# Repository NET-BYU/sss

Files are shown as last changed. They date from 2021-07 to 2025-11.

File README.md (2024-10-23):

# Seven Segment Sign

    

## Welcome to the Seven Segment Sign! (SSS)
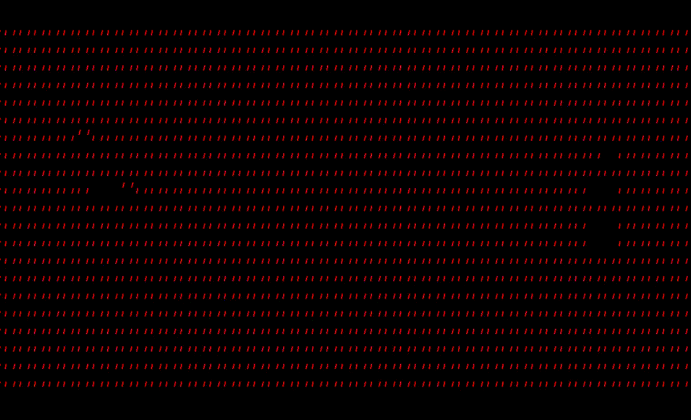
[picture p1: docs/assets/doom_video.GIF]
ricky


## Getting Started
Here are some helpful links to get you up and running!
- [API Docs](https://sss.readthedocs.io/en/latest/API/Display/)
- [Install on Linux/Mac](https://sss.readthedocs.io/en/latest/Installation/Install%20SSS%20on%20Mac%20or%20Linux/)
- [Install on Windows](https://sss.readthedocs.io/en/latest/Installation/Install%20SSS%20on%20Windows/)
- [Create your first demo](https://sss.readthedocs.io/en/latest/Tutorials/Creating%20a%20demo/)

## Common Commands
Although thorough information on how to [get started](https://sss.readthedocs.io/en/latest/Overview/Get%20started/) is in the docs, here are some quick commands you can run in order to get rolling **once you have everything installed**:

- Run the PyGame Simulator for the SSS
  ```bash
  python3 main.py simulator
  ```
- Run a specific demo in the simulator
  ```bash
  python3 main.py demo <demo_name> -s
  ```
- Start the SSS in kiosk mode
  ```bash
  python3 main.py kiosk
  ```
- To view log output of varying degrees, use the `-v` option (the more `v`'s the more `v`erbose the output becomes

For any other help or a list of comprehensive commands, run
```bash
python3 main.py --help
```

## Reporting an Issue
We love feedback! As the SSS codespace expands and acquires new features, we realize that some bugs will fall through the cracks. Please feel free to open a new issue if you notice any bugs in the code, mistakes or missing information in the documentation, or if you want a new feature to be added to the project.

You can go to the **Issues** tab to create a new issue. Please be mindful to choose the correct template for the right type of question. Apart from the currently open issues from before this writing, any **issue that does not conform to the template may become stale or be closed without warning.**

## Submitting a PR
If you are feeling creative and you would like to contribute a demo but you are outside of our organization, you are more than welcome to submit a pull request and we will look it over! 

In order for a pull request to be merged, we have the following three policies:
1. Your code must have adequate, meaningful comments. Don't feel like you have to explain every statement, but also don't write comments like `# This a loop that goes over all the values`.
2. Your PR will need approval from **at least 2 org members**. Users who respond to these the most are @apal6981, @christopolise, and @philipbl
3. Your code **MUST** be formatted with `black`. This is as simple as adding the [Black Formatter](https://marketplace.visualstudio.com/items?itemName=ms-python.black-formatter) to VS/OSS Code or running `python3 -m black <your py files>`

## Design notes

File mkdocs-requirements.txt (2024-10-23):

mkdocs
mkdocs-autorefs
mkdocs-bootstrap386
mkdocs-bootswatch
mkdocs-git-revision-date-localized-plugin
mkdocs-material
mkdocs-material-extensions
mkdocs-rtd-dropdown
mkdocs-windmill-dark
mkdocstrings[python]
griffe

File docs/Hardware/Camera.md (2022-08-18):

The purpose of a camera module exists thanks mainly thanks to the creative camera demo by [Bryson Schiel](https://www.linkedin.com/in/bryson-s-82926aa6/). While any camera which streams to an IP address will work with the demo, we have provided an inexpensive option which integrates nicely with the SSS. This module is centered around the ESP-CAM kit and it's firmware. All of these files are available in the [hw/camera](https://github.com/NET-BYU/sss/tree/docs/hw/camera) directory of the project. All of these files were designed and provided by [Carter Pollan](https://github.com/virginia2244).

## Camera PCB Blueprints

### Backpack Schematic
The ESP-CAM normally comes with its own backpack which provides power. An optional set of pins was included in the design to allow for a peripheral to connect to the camera if necessary. The backpack that we have provides power and also a breakout to connect devices to some of the GPIO pins.

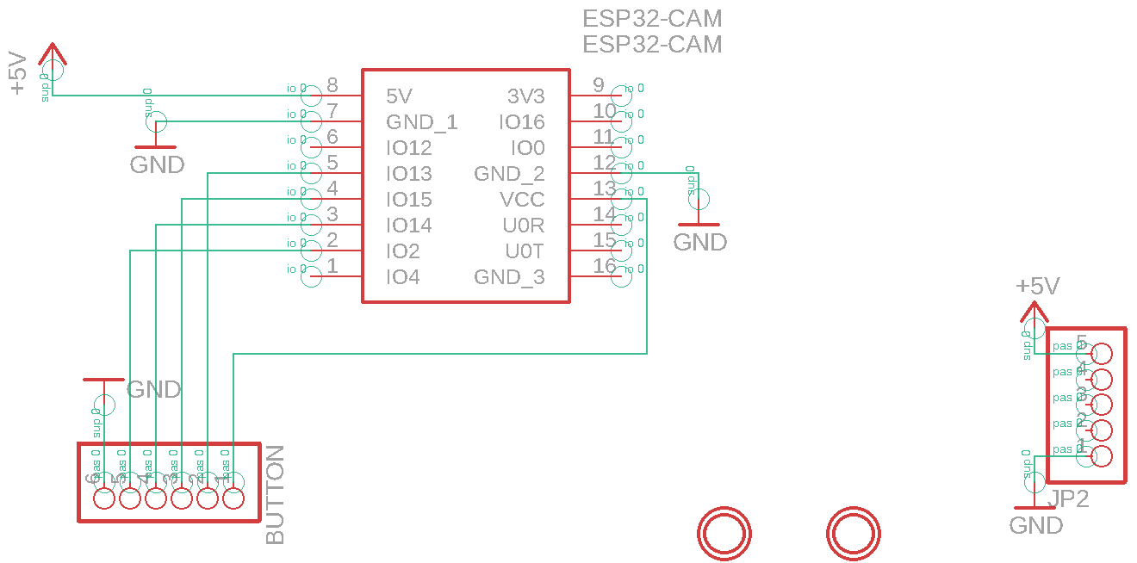
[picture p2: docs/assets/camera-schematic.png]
backpack-sch


### Backpack PCB
This PCB is single-sided and has no vias which means that it can be etched on the most simple of mills. It also features some groovy, curved traces for a nice aesthetic. [Check this video out](https://youtu.be/euJgtLcWWyo) to see why melty boards are superior.

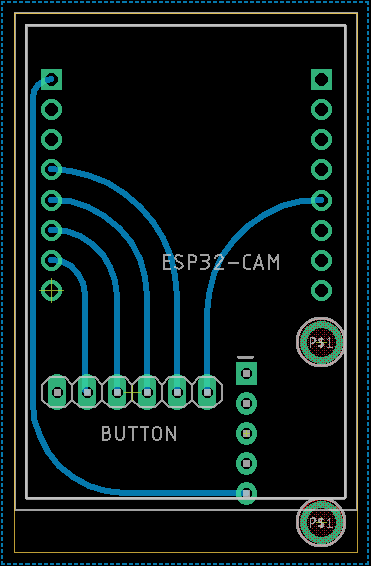
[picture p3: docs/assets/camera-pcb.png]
backpack-pcb


## Camera Enclosure

For those who aren't a big fan of have a jumbled mess of wires and PCBs, a sleek two piece case has also been designed to encapsulate and mount the camera module.  

### Lid

<!-- Import maps polyfill -->
<!-- Remove this when import maps will be widely supported -->
<script async src="https://unpkg.com/es-module-shims@1.3.6/dist/es-module-shims.js"></script>

<script type="importmap">
    {
        "imports": {
            "three": "../../assets/three.module.js"
        }
    }
</script>

<script type="module">

    import * as THREE from 'three';

    import { OrbitControls } from '../../assets/OrbitControls.js';
    import { ThreeMFLoader } from '../../assets/3MFLoader.js';

    let camera, scene, renderer, object, loader, controls;

    var container = document.getElementById('camera-lid');

    init();

    function init() {

        renderer = new THREE.WebGLRenderer( { antialias: true, alpha: true } );
        renderer.setPixelRatio( window.devicePixelRatio );
        renderer.setSize( 500, 300 );
        renderer.setClearColor( 0x000000, 0 ); // the default
        container.appendChild( renderer.domElement );
        renderer.domElement.style.cursor = "grab";

        scene = new THREE.Scene();

        scene.add( new THREE.AmbientLight( 0xffffff, 0.2 ) );

        camera = new THREE.PerspectiveCamera( 15, window.innerWidth / window.innerHeight, 1, 500 );

        // Z is up for objects intended to be 3D printed.

        camera.up.set( 0, 0, 1 );
        camera.position.set( - 100, - 250, 100 );
        scene.add( camera );

        controls = new OrbitControls( camera, renderer.domElement );
        controls.addEventListener( 'change', render );
        controls.minDistance = 50;
        controls.maxDistance = 400;
        controls.enablePan = false;
        controls.update();

        const pointLight = new THREE.PointLight( 0xffffff, 0.8 );
        camera.add( pointLight );

        const manager = new THREE.LoadingManager();

        manager.onLoad = function () {

            const aabb = new THREE.Box3().setFromObject( object );
            const center = aabb.getCenter( new THREE.Vector3() );

            object.position.x += ( object.position.x - center.x );
            object.position.y += ( object.position.y - center.y );
            object.position.z += ( object.position.z - center.z );

            controls.reset();

            scene.add( object );
            render();

        };

        loader = new ThreeMFLoader( manager );
        loadAsset( '../../assets/cam-lid-sss.3mf' );

        // window.addEventListener( 'resize', onWindowResize );

    }

    function loadAsset( asset ) {

        loader.load( asset, function ( group ) {

            if ( object ) {

                object.traverse( function ( child ) {

                    if ( child.material ) child.material.dispose();
                    if ( child.material && child.material.map ) child.material.map.dispose();
                    if ( child.geometry ) child.geometry.dispose();

                } );

                scene.remove( object );

            }

            object = group;

        } );

    }

    function onWindowResize() {

        camera.aspect = window.innerWidth / window.innerHeight;
        camera.updateProjectionMatrix();

        renderer.setSize( window.innerWidth, window.innerHeight );

        render();

    }

    function render() {

        renderer.render( scene, camera );

    }

</script>

<script type="module">

    import * as THREE from 'three';

    import { OrbitControls } from '../../assets/OrbitControls.js';
    import { ThreeMFLoader } from '../../assets/3MFLoader.js';

    let camera, scene, renderer, object, loader, controls;

    var container = document.getElementById('camera-body');

    init();

    function init() {

        renderer = new THREE.WebGLRenderer( { antialias: true, alpha: true } );
        renderer.setPixelRatio( window.devicePixelRatio );
        renderer.setSize( 500, 300 );
        renderer.setClearColor( 0x000000, 0 ); // the default
        container.appendChild( renderer.domElement );
        renderer.domElement.style.cursor = "grab";

        scene = new THREE.Scene();

        scene.add( new THREE.AmbientLight( 0xffffff, 0.2 ) );

        camera = new THREE.PerspectiveCamera( 15, window.innerWidth / window.innerHeight, 1, 500 );

        // Z is up for objects intended to be 3D printed.

        camera.up.set( 0, 0, 1 );
        camera.position.set( - 100, - 250, 100 );
        scene.add( camera );

        controls = new OrbitControls( camera, renderer.domElement );
        controls.addEventListener( 'change', render );
        controls.minDistance = 50;
        controls.maxDistance = 400;
        controls.enablePan = false;
        controls.update();

        const pointLight = new THREE.PointLight( 0xffffff, 0.8 );
        camera.add( pointLight );

        const manager = new THREE.LoadingManager();

        manager.onLoad = function () {

            const aabb = new THREE.Box3().setFromObject( object );
            const center = aabb.getCenter( new THREE.Vector3() );

            object.position.x += ( object.position.x - center.x );
            object.position.y += ( object.position.y - center.y );
            object.position.z += ( object.position.z - center.z );

            controls.reset();

            scene.add( object );
            render();

        };

        loader = new ThreeMFLoader( manager );
        loadAsset( '../../assets/cam-case-sss.3mf' );

        // window.addEventListener( 'resize', onWindowResize );

    }

    function loadAsset( asset ) {

        loader.load( asset, function ( group ) {

            if ( object ) {

                object.traverse( function ( child ) {

                    if ( child.material ) child.material.dispose();
                    if ( child.material && child.material.map ) child.material.map.dispose();
                    if ( child.geometry ) child.geometry.dispose();

                } );

                scene.remove( object );

            }

            object = group;

        } );

    }

    function onWindowResize() {

        camera.aspect = window.innerWidth / window.innerHeight;
        camera.updateProjectionMatrix();

        renderer.setSize( window.innerWidth, window.innerHeight );

        render();

    }

    function render() {

        renderer.render( scene, camera );

    }

</script>

<span>

### Case

</span>

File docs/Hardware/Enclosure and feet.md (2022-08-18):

## Enclosure

The enclosure for the physical SSS is made out of two an acryllic (**NOT POLYCARBONATE**) plexiglass fastened together by 18 x M3 screws in a 20mm standoff. The SVG files in [hw/enclosure](https://github.com/NET-BYU/sss/tree/docs/hw/enclosure) can be loaded onto a plasma/laser cutter to create the pieces.

### Front Piece
The shape and the mounting holes are seen in this figure below:

enclosure-front-sss

### Back Piece
The shape and the mounting holes are also seen on this piece. The upper group of 4 holes in the center allows for the mounting of a Raspberry Pi. The lower five are mounting holes for the [power and breakout board](Power%20Board.md). The slender slots allow for [resistors soldered to the `clk` and `din` pins](Panel.md) to poke out while the larger openings allow for the commnication and power cable to plug into the SSS's panels.

enclosure-back-sss

## Feet

The feet for the SSS are 3D printed pieces that allow for each panel (both front and back) to insert and stand inside it. The more feet are put on the bottom of the enclosure, the more stable it will be.

<script async src="https://unpkg.com/es-module-shims@1.3.6/dist/es-module-shims.js"></script>

<script type="importmap">
    {
        "imports": {
            "three": "../../assets/three.module.js"
        }
    }
</script>

<script type="module">

    import * as THREE from 'three';

    import { OrbitControls } from '../../assets/OrbitControls.js';
    import { ThreeMFLoader } from '../../assets/3MFLoader.js';

    let camera, scene, renderer, object, loader, controls;

    var container = document.getElementById('camera-lid');

    init();

    function init() {

        renderer = new THREE.WebGLRenderer( { antialias: true, alpha: true } );
        renderer.setPixelRatio( window.devicePixelRatio );
        renderer.setSize( 500, 300 );
        renderer.setClearColor( 0x000000, 0 ); // the default
        container.appendChild( renderer.domElement );
        renderer.domElement.style.cursor = "grab";

        scene = new THREE.Scene();

        scene.add( new THREE.AmbientLight( 0xffffff, 0.2 ) );

        camera = new THREE.PerspectiveCamera( 15, window.innerWidth / window.innerHeight, 1, 500 );

        // Z is up for objects intended to be 3D printed.

        camera.up.set( 0, 0, 1 );
        camera.position.set( - 100, - 250, 100 );
        scene.add( camera );

        controls = new OrbitControls( camera, renderer.domElement );
        controls.addEventListener( 'change', render );
        controls.minDistance = 50;
        controls.maxDistance = 400;
        controls.enablePan = false;
        controls.update();

        const pointLight = new THREE.PointLight( 0xffffff, 0.8 );
        camera.add( pointLight );

        const manager = new THREE.LoadingManager();

        manager.onLoad = function () {

            const aabb = new THREE.Box3().setFromObject( object );
            const center = aabb.getCenter( new THREE.Vector3() );

            object.position.x += ( object.position.x - center.x );
            object.position.y += ( object.position.y - center.y );
            object.position.z += ( object.position.z - center.z );

            controls.reset();

            scene.add( object );
            render();

        };

        loader = new ThreeMFLoader( manager );
        loadAsset( '../../assets/feet-sss.3mf' );

        // window.addEventListener( 'resize', onWindowResize );

    }

    function loadAsset( asset ) {

        loader.load( asset, function ( group ) {

            if ( object ) {

                object.traverse( function ( child ) {

                    if ( child.material ) child.material.dispose();
                    if ( child.material && child.material.map ) child.material.map.dispose();
                    if ( child.geometry ) child.geometry.dispose();

                } );

                scene.remove( object );

            }

            object = group;

        } );

    }

    function onWindowResize() {

        camera.aspect = window.innerWidth / window.innerHeight;
        camera.updateProjectionMatrix();

        renderer.setSize( window.innerWidth, window.innerHeight );

        render();

    }

    function render() {

        renderer.render( scene, camera );

    }

</script>

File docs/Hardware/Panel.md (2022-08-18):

The panels of the SSS are the crux of its hardware. If you are going to attempt to replicate the SSS, it is recommended that you look at the the [Known Problems](#known-problems) and address some of those issues. However, for history and current hardware maintenance sake, we will include the current design of the panels.

## Panel PCB Blueprints

### Panel Schematics

Each panel has a group of 12 [MAX7219](https://www.maximintegrated.com/en/products/power/display-power-control/MAX7219.html) led drivers which control 8 seven segment digits. All of the ICs receive the CS, SCLK, VCC, and GND from a common trace. The MOSI coming from the Raspberry Pi enters into the first IC and is passed through all of them by tying the DOUT (output) of the preceding IC to the DIN (input). The start of the bus for the panel (SV1) receives the following from the [power board](Power%20Board.md):

1. GND
2. LOAD (CS)
3. CLK (SCLK)
4. DIN (MOSI)
5. VCC

Originally, the panels were going to be connected together by connecting the busses by having a corresponding 5 pins out (SV2) to connect to the next panel's 5 pins in (SV1). This design made the traces very long and was susceptible to noise and caused a lot of screen artifacts. Instead, each panel receives info from the [power board](Power%20Board.md) via a cable which plugs into the beginning connector of the bus.

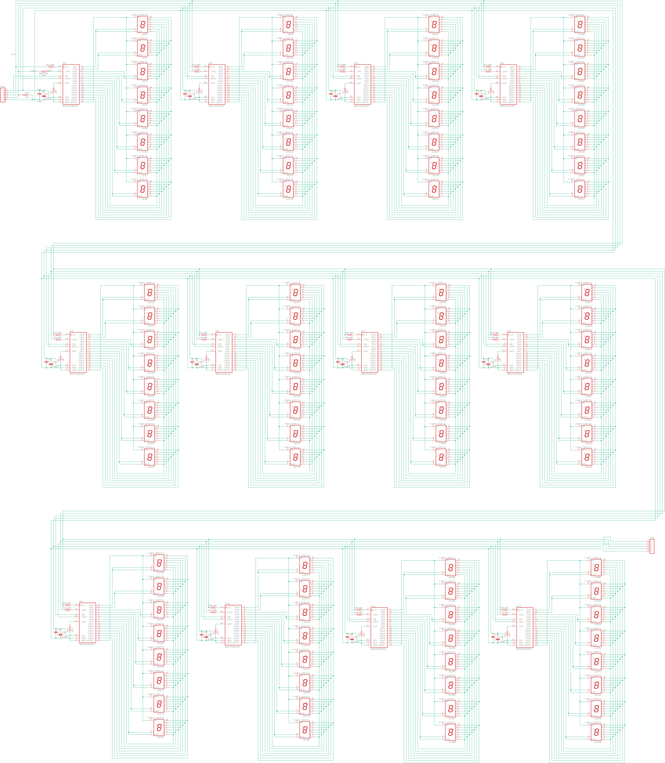
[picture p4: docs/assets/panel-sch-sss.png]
panel-sch-sss


_**Not shown in schematic:** each SCLK and DIN pin on the IC has a resistor of 200Ω+ between it and the trace. This is a hack and should be dealt with in a future hardware design version._

### Panel PCB

The PCB design is a double-sided board. The backside is where the 12 ICs, 12 resistors, 24 capacitors, and 2 cable headers are mounted. The frontside is where the 96 seven segment LED digits are mounted.

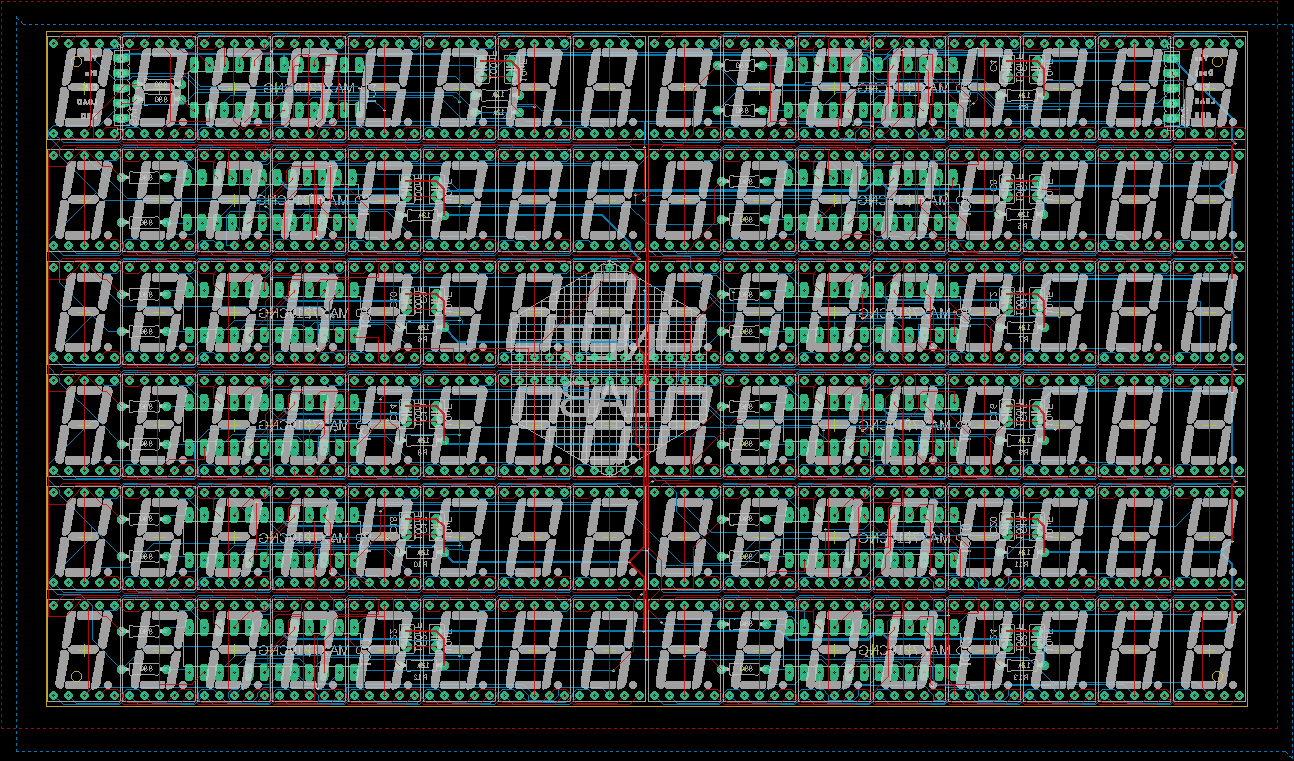
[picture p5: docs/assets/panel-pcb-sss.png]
panel-pcb-sss


### Panel

This is the back view of manufactured panel. Note that the SV1 input from the [power board](Power%20Board.md) is on the right hand side of the board and that the set of output pin pads need not be used.

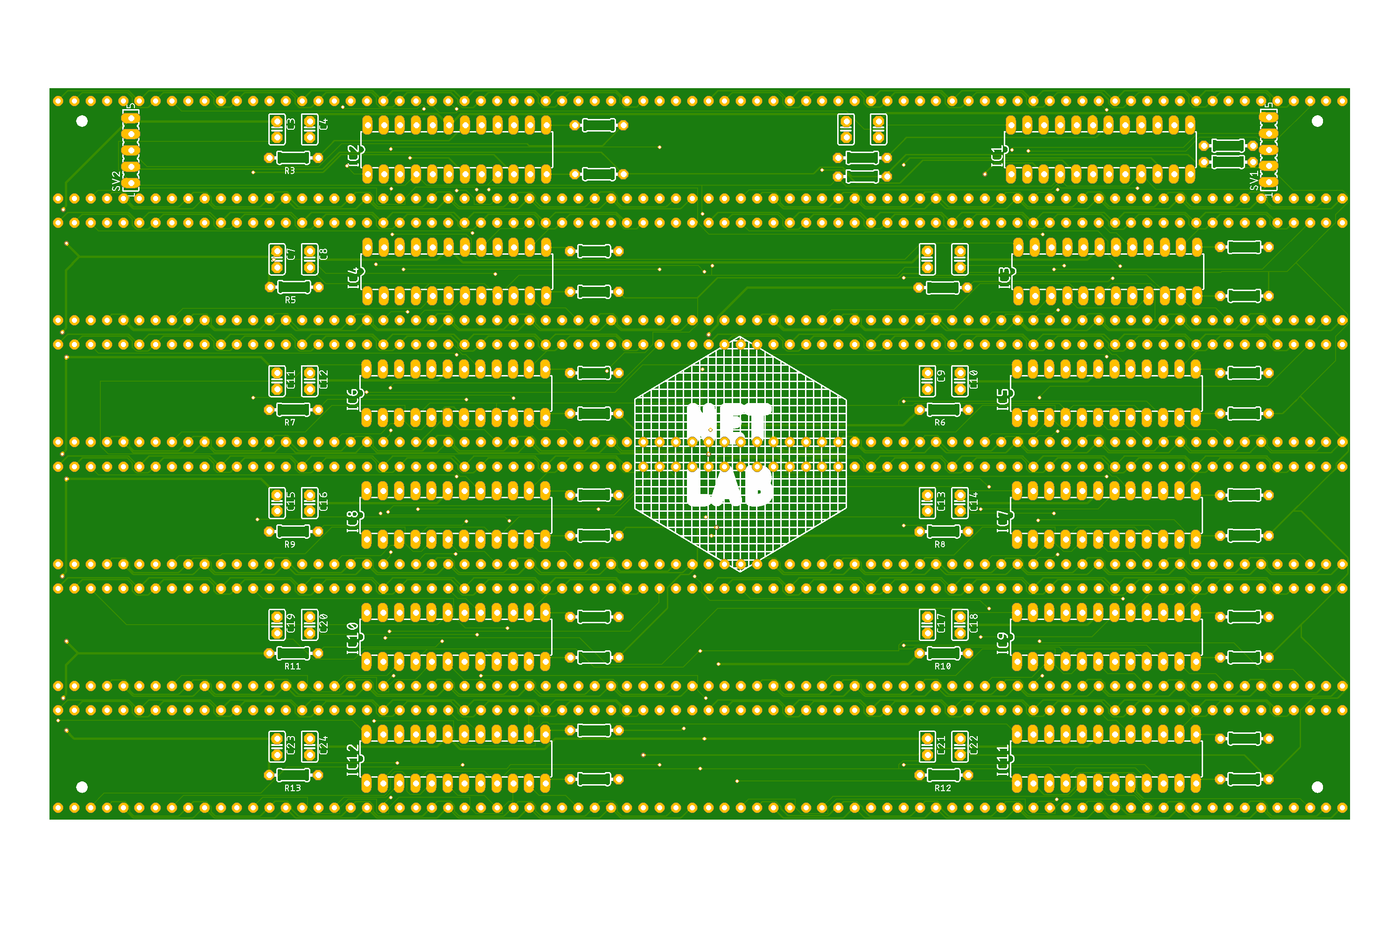
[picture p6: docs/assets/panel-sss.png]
panel-sss


## Known Problems

The current version of the SSS panel is flawed. Among the known problems are:

 - The output pins are not needed
 - The data and clock traces are very long, thin, and susceptible to noise. Changing the trace widths and paths would be necessary.
 - Using some sort of differential grounding might also reduce overall board noise.

 Any efforts to redesign the panels are more than welcome!

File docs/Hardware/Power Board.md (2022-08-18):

## Power Board PCB Blueprints

The power board is a breakout board which takes the SPI protocol wires from the [Raspberry Pi IO](Raspberry%20Pi%20IO.md) and passes them on to the each of the individual [panels](Panel.md). Along with the SPI protocol wires, this board will also power the SSS panels.

### Power Board Schematics

The power board receives all of the Raspberry Pi IO on its 8 x 2 Raspberry Pi headers and reroutes them to the BOARD_n headers. These BOARD_n pins will connect to the SV1 pins on the panels. There is also a barrel jack on this board where a DC adapter that outputs 5V and 4A will supply power to all of the ICs and LED seven segment digits on the panels of the SSS.

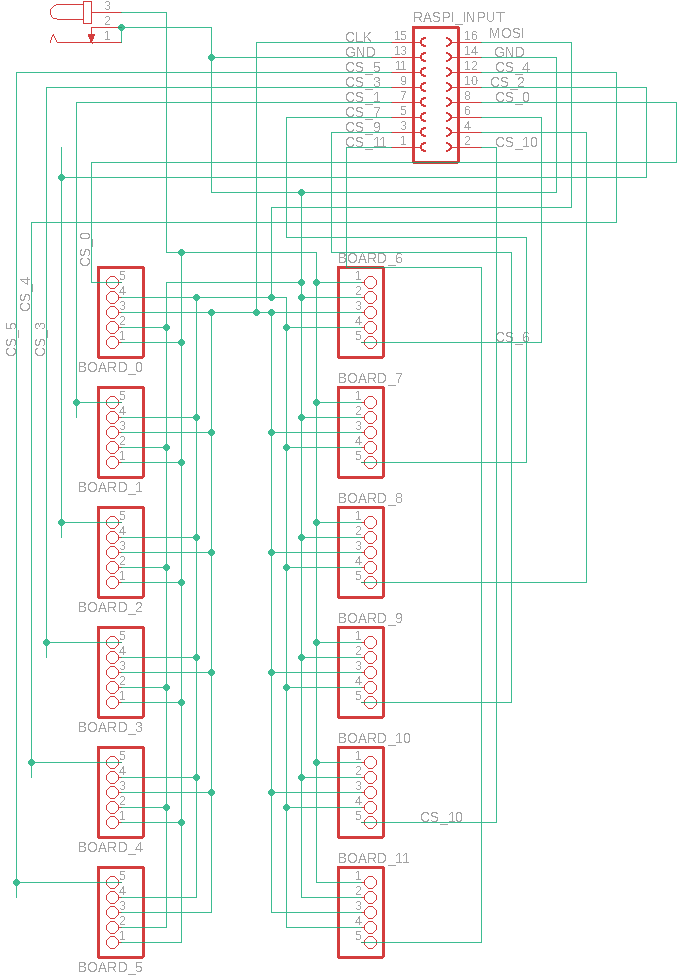
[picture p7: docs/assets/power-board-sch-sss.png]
power-board-sch-sss


### Power Board PCB
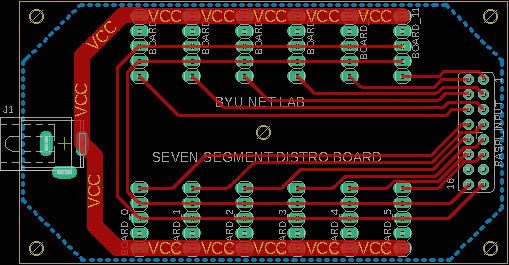
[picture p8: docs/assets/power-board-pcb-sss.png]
power-board-pcb-sss


### Power Board
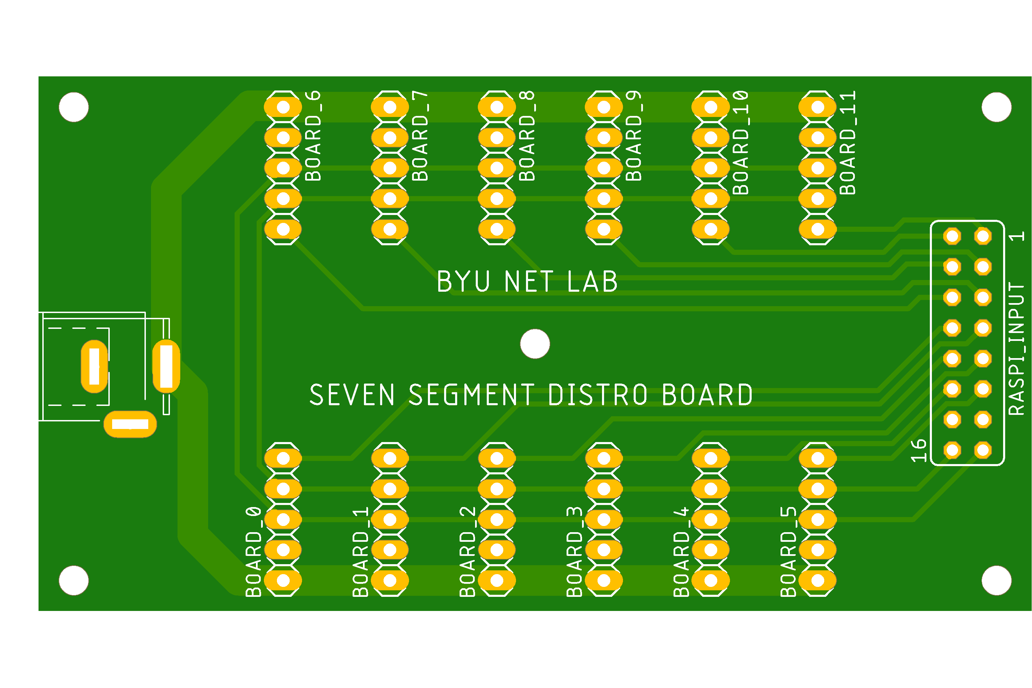
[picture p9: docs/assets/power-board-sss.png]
power-board-sss


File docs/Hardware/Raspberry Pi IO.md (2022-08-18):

At the center of the SSS is the Raspberry Pi, a compact, inexpensive computer that has a very accessible hardware interface. The SSS takes advantage of this interface and connects to all of its [panels](Panel.md) through the Pi's GPIO. Checkout this [link](https://pinout.xyz) to get an interactive guide to the GPIO.

## SPI Interface
The communication protocol the SSS uses to draw to all of the panels is the Serial Peripheral Interface (or SPI for short). We won't go into the [exact details](https://www.circuitbasics.com/basics-of-the-spi-communication-protocol/) of how this protocol works, but suffice it to say there are several connections necessary to make this work:

- **MOSI (Master Out Slave In)**: The actual binary instruction which tell the panel what to draw to the screen.
- **CS (Chip Select)**: This wire has to be on (or high) in order to receive and apply instructions from MOSI. There is one of these for each panel in our project.
- **SCLK (Clock Signal)**: This wire has an oscillating high-low timing signal that helps all the CS wires and MOSI stay in sync with each other.

## Device Tree Overlay
As you start exploring the Raspberry Pi GPIO its SPI busses (or groups of pins meant to act as a SPI device) you'll notice they only have 1 or 2 CS pins max. This means that by default, a Raspberry Pi can talk to two separate devices (or in our case, panels) at a time. This becomes a problem considering that the SSS has 12 panels!

We can overcome this problem by reassigning some of the GPIO pins on the Pi to be CS pins for our SPI bus. To do this, we will need to create a device tree overlay, or a special configuration file which reminds the Raspberry Pi's operating system on startup to make these changes to the pin definitions.

### Creating the Device Tree Source file

For those who are interested to see how this works, please refer to the [official documentation](https://www.raspberrypi.com/documentation/computers/configuration.html#device-trees-overlays-and-parameters) from Raspberry Pi on how to create a valid device tree source (`dts`) file and compile it. [sss.dts](https://raw.githubusercontent.com/NET-BYU/sss/docs/dts/sss.dts) has been provided for those who wish to copy the same configuration as the original SSS or to use it as reference.

A brief summary of what is accomplished in the file, the reassigning of certain GPIO pins, is depicted in the table below and can be used as reference in creating altered `dts` files:

#### GPIO to CS for SPI Bus 0 Reassignment
<table>
  <tr>
    <th>GPIO Pin</th>
    <td>6</td>
    <td>13</td>
    <td>19</td>
    <td>26</td>
    <td>25</td>
    <td>1</td>
    <td>12</td>
    <td>16</td>
    <td>20</td>
    <td>21</td>
    <td>17</td>
    <td>27</td>
    <td>22</td>
  </tr>
  <tr>
    <th>CS No.</th>
    <td>2</td>
    <td>3</td>
    <td>4</td>
    <td>5</td>
    <td>6</td>
    <td>7</td>
    <td>8</td>
    <td>9</td>
    <td>10</td>
    <td>11</td>
    <td>12</td>
    <td>13</td>
    <td>14</td>
  </tr>
</table>

### Compiling the `dts` into a `dtbo`
After a correctly formatted `dts` is made, it needs to be compiled into a device tree blob overlay (`dtbo`). This is a binary file is referred to upon boot and makes the appropriate changes in pin definition.

To compile the `dts` file:
```bash
dtc -@ -I dts -O dtb -o sss.dtbo sss.dts
```

After the `dtbo` binary is created, it needs to be moved or copied into the directory where GPIO overlays for the Pis are held:

```bash
sudo cp sss.dtbo /boot/overlays
```

Finally we will edit the boot config file to let the Pi know that we want to apply the overlay we just created:

```bash
sudo nano /boot/config.txt
```

Add this line to the file, notice how the first field of the assigned value to `dtoverlay` is our desired `dtbo` file name and the rest of the `cs<num>_pin` correspond to the table in the previous section.

```
dtoverlay=sss,cs2_pin=6,cs3_pin=13,cs4_pin=19,cs5_pin=26,cs6_pin=25,cs7_pin=1,cs8_pin=12,cs9_pin=16,cs10_pin=20,cs11_pin=21,cs12_pin=17,cs13_pin=27,cs14_pin=22
```

Now reboot your device and the changes should take effect!

## Pi Wiring

In our build of the SSS we connected the GPIO of the Raspberry Pi to a breakout board which distributes the CS signal to its respective panel and the MOSI, SCLK, GND, and VCC signals to the rest.



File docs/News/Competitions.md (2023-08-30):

## BYU IT&CSA 2022 Raspberry Pi Competition

The SSS was presented at the BYU IT&CSA 2022 Raspberry Pi competition with efforts to convince judges of its practical, educational, and IoT capabilities. Ashton Palacios and Chris Kitras represented the original team of contributors at the event and took first prize.

<figure class="image mx-auto" style="max-width: 750px">
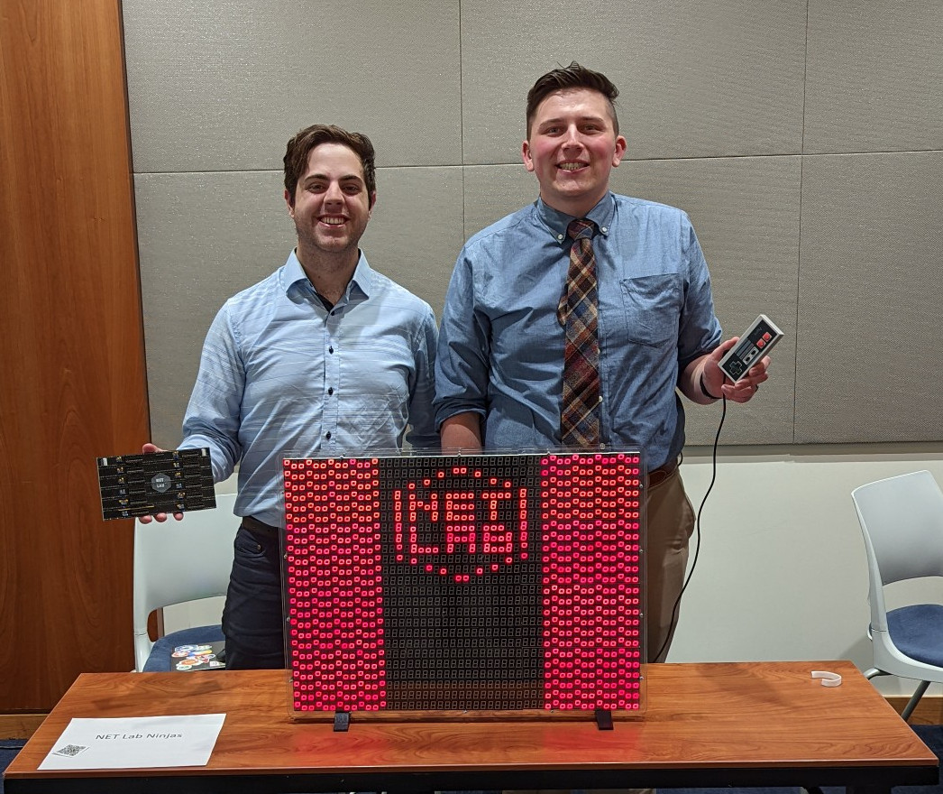
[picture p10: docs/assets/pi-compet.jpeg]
Units of the course.
  
  <figcaption style="text-align: center;">Chris Kitras (left) holding a single panel of the SSS and Ashton Palacios (right) holding an NES controller which is one possible input for the SSS.</figcaption>
</figure>

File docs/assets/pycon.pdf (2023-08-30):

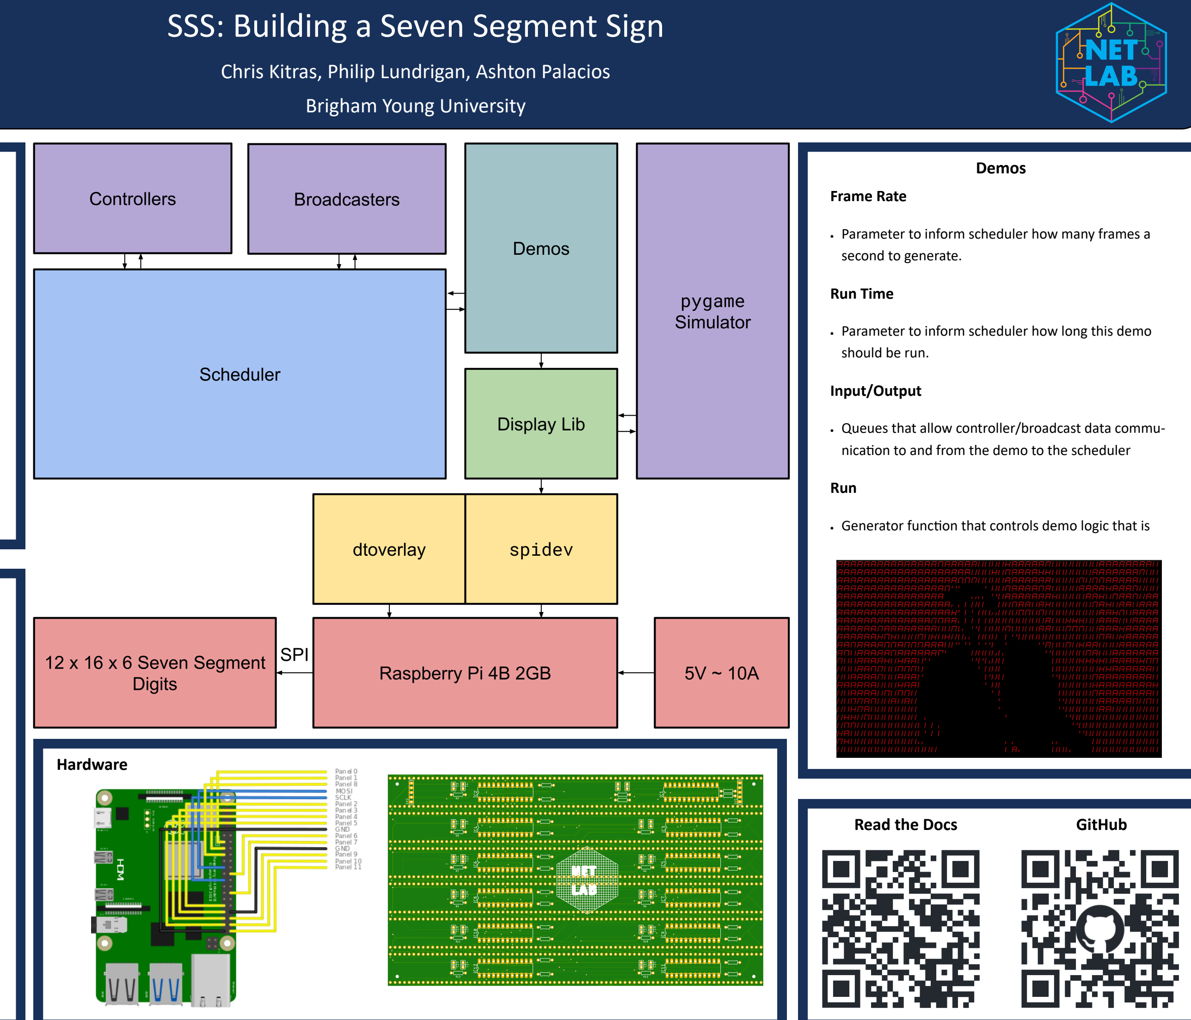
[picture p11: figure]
SSS: Building a Seven Segment Sign; Brigham Young University; Read the Docs; GitHub; Demos; Frame Rate; second to generate.; Run Time; should be run.; Input/Output; Run; Hardware

## Chris Kitras, Philip Lundrigan, Ashton Palacios

Architecture

Scheduler:

- Generators are the core underpinnings of our system. The scheduler calls each subsystem’s run/tick function which quickly performs a single action and yields control back to the scheduler.

Controllers:

- Demos can have input ranging from a physical game controller to a web based app.

Broadcasters:

- Demo and system outputs can be broadcast over the internet to different services.

Display Library:

- Custom Python library that abstracts away drawing to a physical screen or simulated pygame screen.

Introduction

Using a Raspberry Pi, 1152 seven-segment displays, and Python, we built a Seven Segment Sign (SSS). The project is designed to make something familiar and boring (seven-segment displays) into something remarkable. We designed a modular circuit board that combines hundreds of displays into one cohesive display. We created a Python library to abstract all of the hardware details of the sign to make it easy for new Python developers to write applications for the SSS. We have created multiple games and demos to show what the SSS can do. And, of course, we even ported Doom. We make extensive use of Python generators to design our system. We made our system modular so that it can receive input from multiple sources, like a game controller or the network using a smartphone.

- Parameter to inform scheduler how many frames a
- Parameter to inform scheduler how long this demo
- Queues that allow controller/broadcast data communication to and from the demo to the scheduler
- Generator function that controls demo logic that is

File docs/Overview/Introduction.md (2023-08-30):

# Introduction

The Seven Segment Sign, or SSS for short, is a purely Python, Raspberry Pi-powered system that drives a screen of 1152 seven segment digits (arranged in a 48 x 24 array). But don't let these low specs fool you! This platform provides a beginner-friendly opportunity for anyone to learn how to address complex design problems with strict limitations. Some of the initial demos we've been able to make work are:

### Video Player

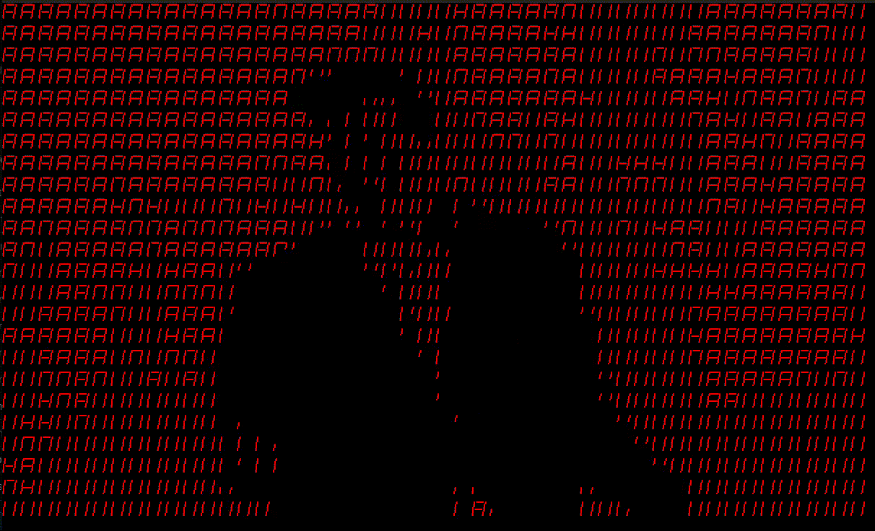
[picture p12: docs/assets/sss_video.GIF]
video


### Arcade Games

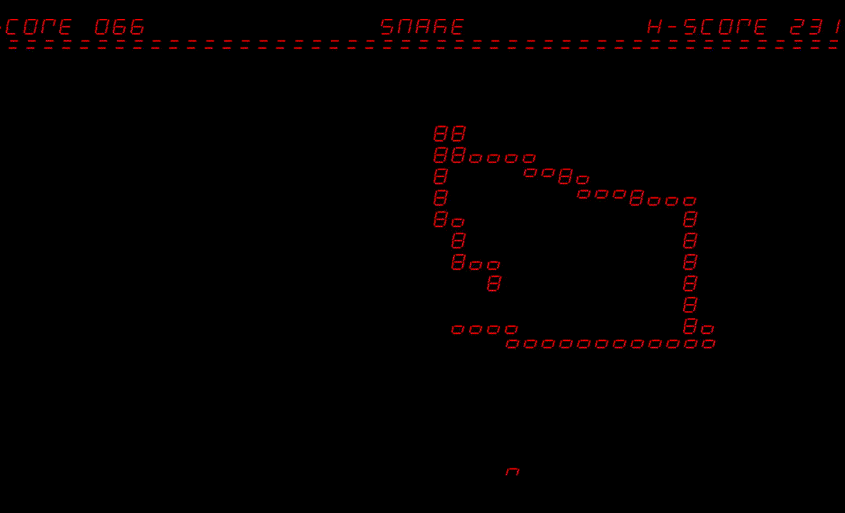
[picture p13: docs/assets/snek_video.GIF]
snek


### and even Doom!

doom

## What next?
 Even though the physical SSS resides in the [BYU NET Lab](https://netlab.byu.edu), the source code, blueprints, and a simulator are all available on [GitHub](https://www.github.com/NET-BYU/sss) and this wiki! 
 
 Take a look at the following links to help you get started:

 - [Get started](Get%20started.md)
 - [Support](../Troubleshooting/Support.md)

Happy hacking!

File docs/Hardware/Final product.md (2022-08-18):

## Front of SSS

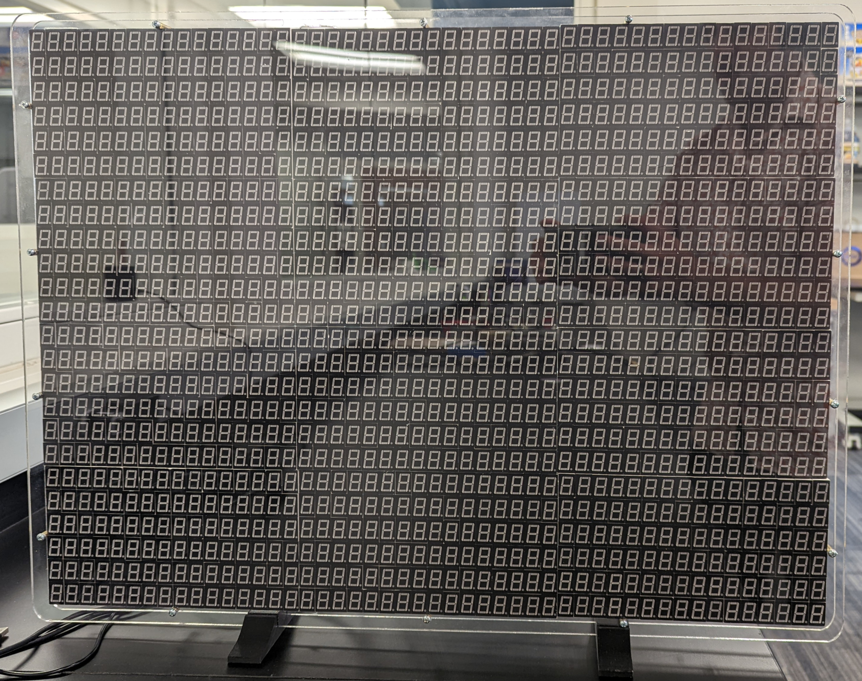
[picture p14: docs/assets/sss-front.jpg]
sss-front


## Back of SSS

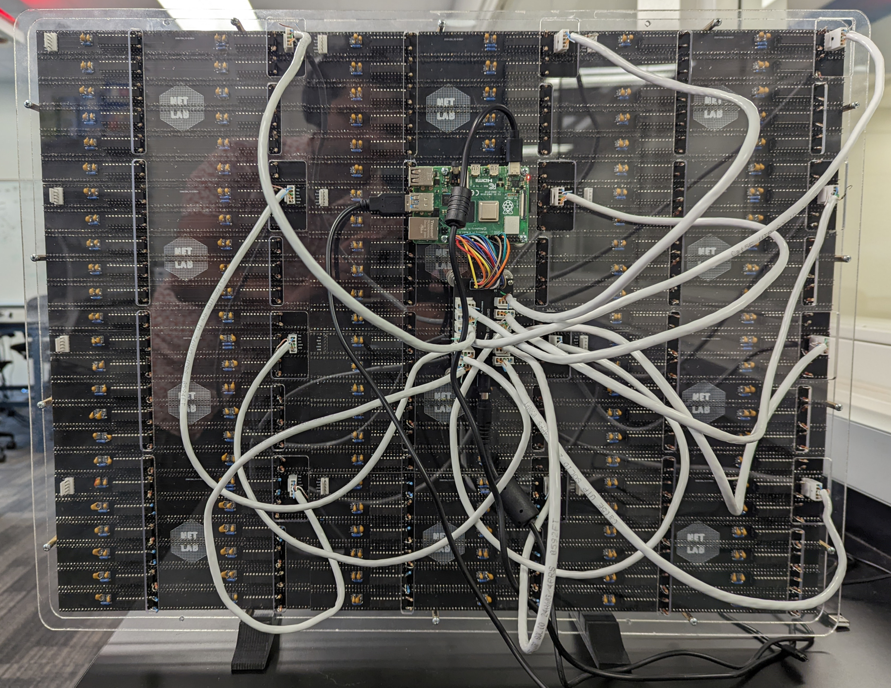
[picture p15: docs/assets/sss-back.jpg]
sss-back


## SSS in Action

sss-lab

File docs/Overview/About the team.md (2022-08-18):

Since its inception at the end of summer in 2021 the list of contributors for the SSS has grown significantly. The first version of the system and winner of the BYU IT&CSA Raspberry Pi 2021 competition was designed and developed by [Dinah Bronson](https://www.linkedin.com/in/dinah-squire-3a84831b5/), [Ashton Palacios](https://www.linkedin.com/in/ashton-palacios/), [Chris Kitras](https://www.linkedin.com/in/christopher-kitras/), and [Phil Lundrigan](https://www.linkedin.com/in/philipbl/). 

Since that first edition, the number of [contributors](https://github.com/NET-BYU/sss/graphs/contributors) has doubled mainly with new researchers from the [BYU NET Lab](https://netlab.byu.edu/people/), each contributing one or more unique demos!

If you are interested in helping the maintain or develop for the SSS, feel free to open a PR and [get started](../Overview/Get%20started.md) by [creating a demo](../Tutorials/Creating%20a%20demo.md).

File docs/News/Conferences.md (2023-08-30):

## PyCon US 2023

The SSS was presented at the PyCon US 2023 conference along with a poster with the aim to show off a hardware system that can be used to teach Python to students and control different hardware interfaces. Many people were excited to see the sign and were delighted that they came all the way to Salt Lake City to get rickrolled in a low resolution.

<figure class="image mx-auto" style="max-width: 750px">
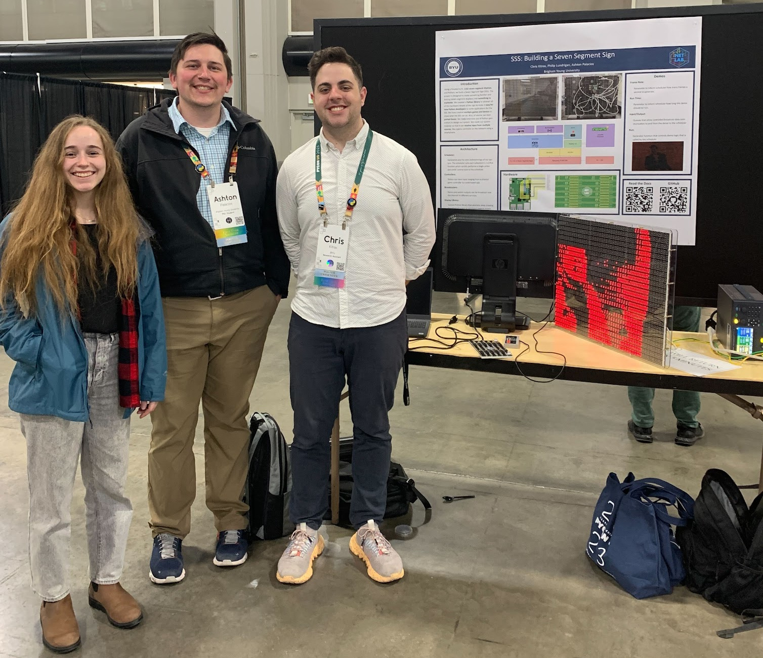
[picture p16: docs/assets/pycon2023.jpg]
Units of the course.
  
  <figcaption style="text-align: center;">Laura Landon (left), Ashton Palacios (center), and Chris Kitras (right) presenting the SSS</figcaption>
</figure>

### Poster
<object data="../../assets/pycon.pdf" type="application/pdf" width="100%" height="700px">
    <embed src="../../assets/pycon.pdf">
        <p>This browser does not support PDFs. Please download the PDF to view it: <a href="../../assets/pycon.pdf">Download PDF</a>.</p>
    </embed>
</object>

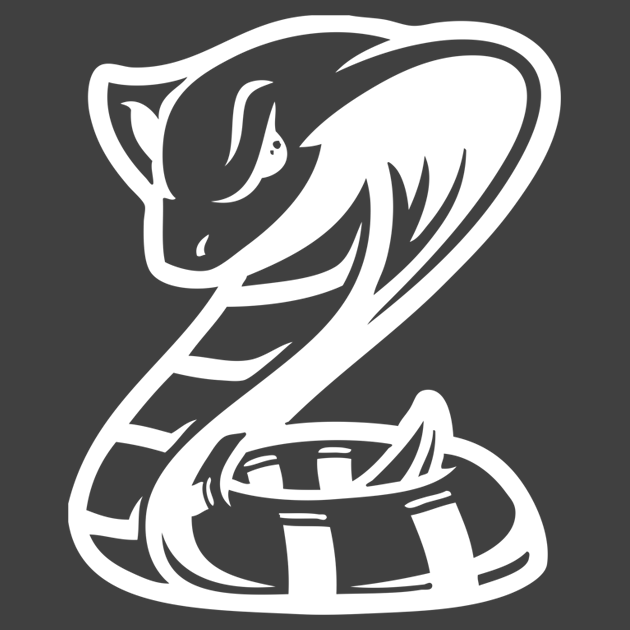
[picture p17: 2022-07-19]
docs/assets/sss.png

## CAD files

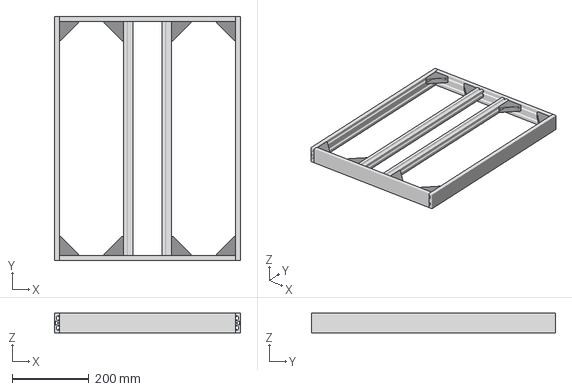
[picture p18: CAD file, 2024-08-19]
hw/case/10 Series/Frame Assembly v7.3mf
484.4 x 635.4 x 50.8 mm

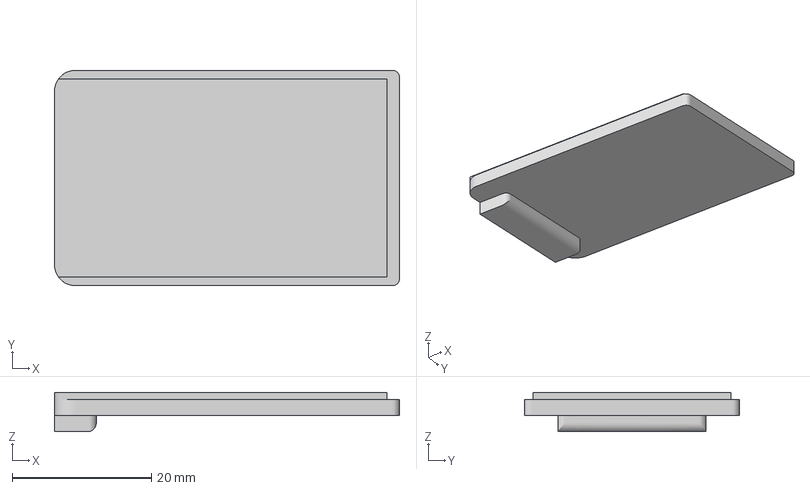
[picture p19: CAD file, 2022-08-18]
docs/assets/cam-lid-sss.3mf
49.5 x 30.9 x 5.65 mm

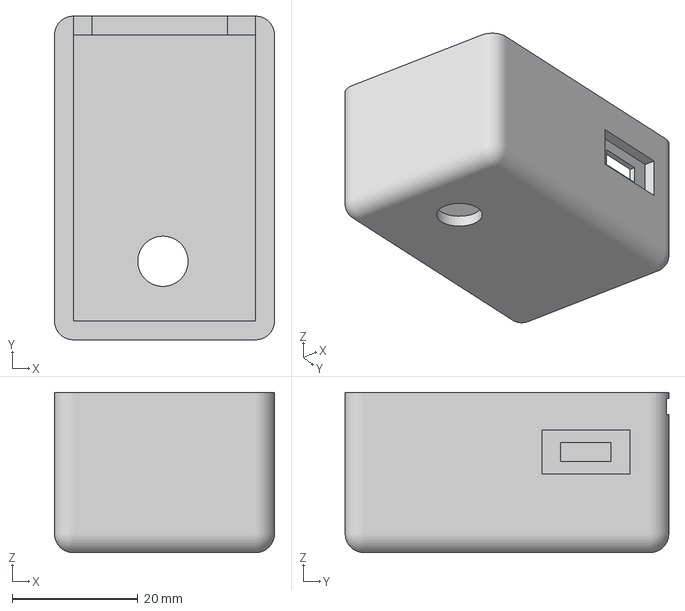
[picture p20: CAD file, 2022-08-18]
hw/camera/cam-case-sss.3mf
35.0 x 51.5 x 25.5 mm

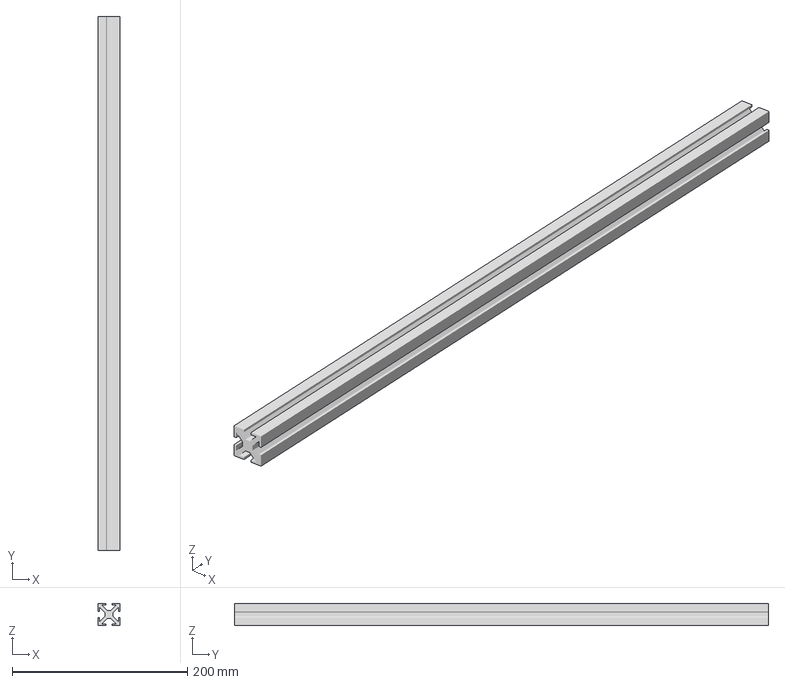
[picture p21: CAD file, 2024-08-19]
hw/case/10 Series/TS10-10 v5.3mf
25.4 x 609.3 x 25.4 mm

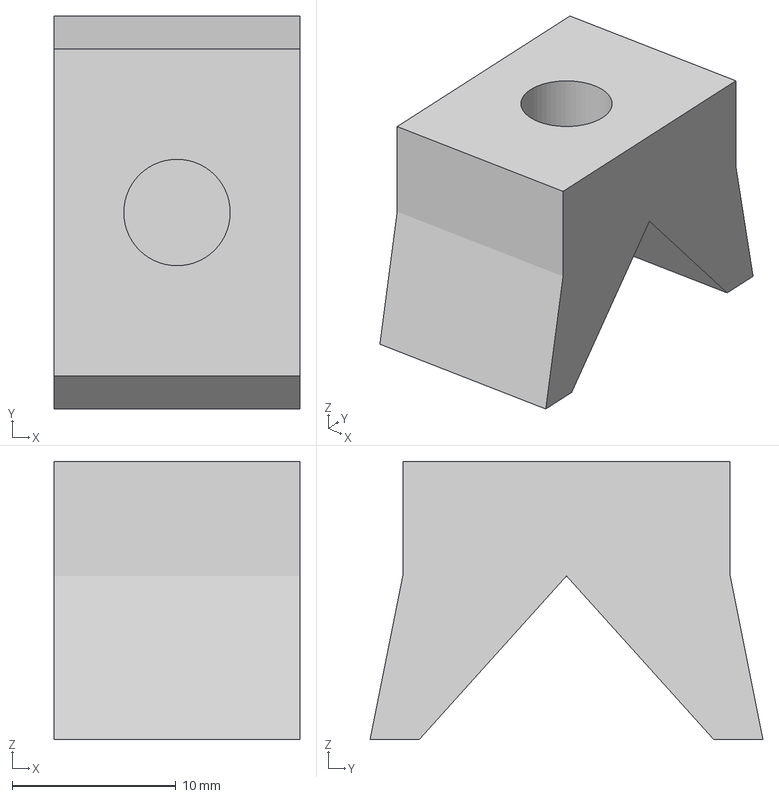
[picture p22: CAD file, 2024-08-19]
hw/case/Brackets/Spacer 1 v4.3mf
15.0 x 24.0 x 17.0 mm

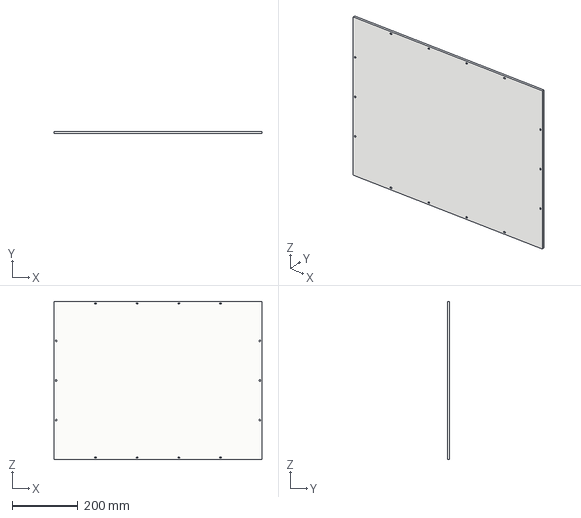
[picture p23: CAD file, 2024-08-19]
hw/case/Front Acrylic v13.3mf
635.0 x 6.35 x 483.5 mm

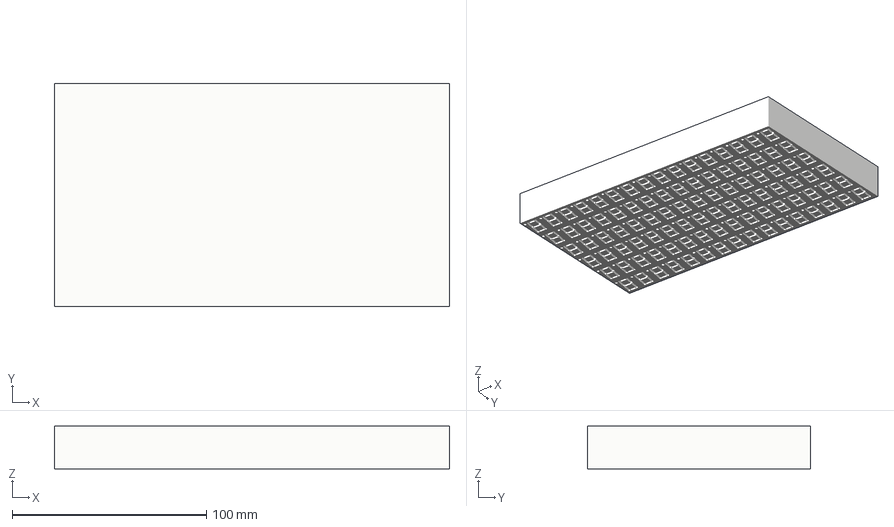
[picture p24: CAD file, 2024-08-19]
hw/case/Panels/Single Panel v19.3mf
203.3 x 114.8 x 22.0 mm

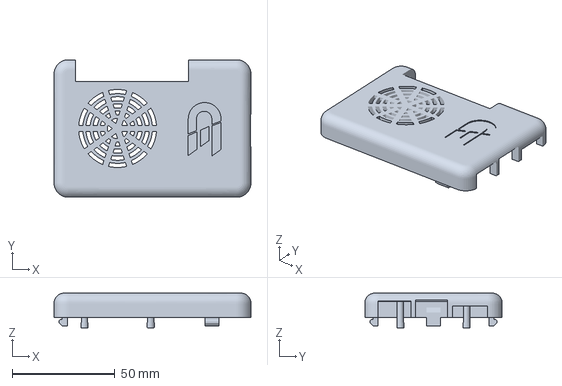
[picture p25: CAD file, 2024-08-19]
hw/case/Pi/TOP BODY v8.3mf
96.0 x 67.0 x 17.0 mm

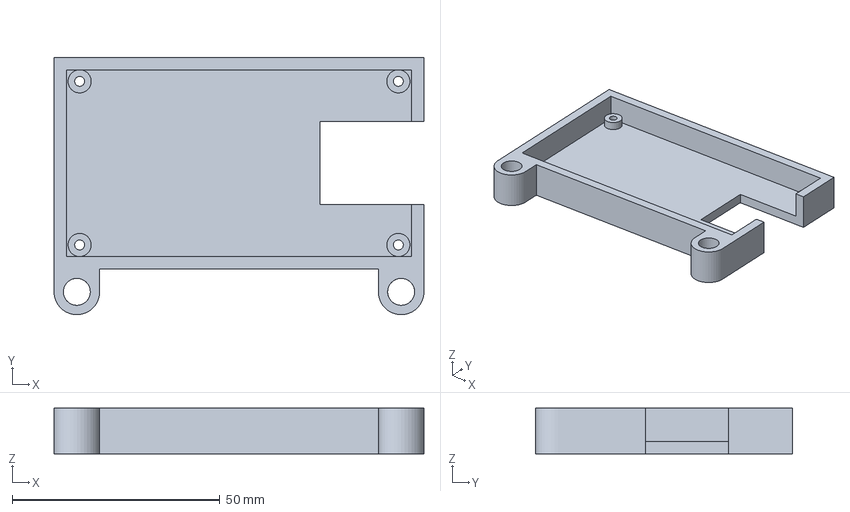
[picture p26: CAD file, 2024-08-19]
hw/case/Power Distribution Board/Power Distribution Board Case v10.3mf
89.0 x 62.0 x 11.0 mm

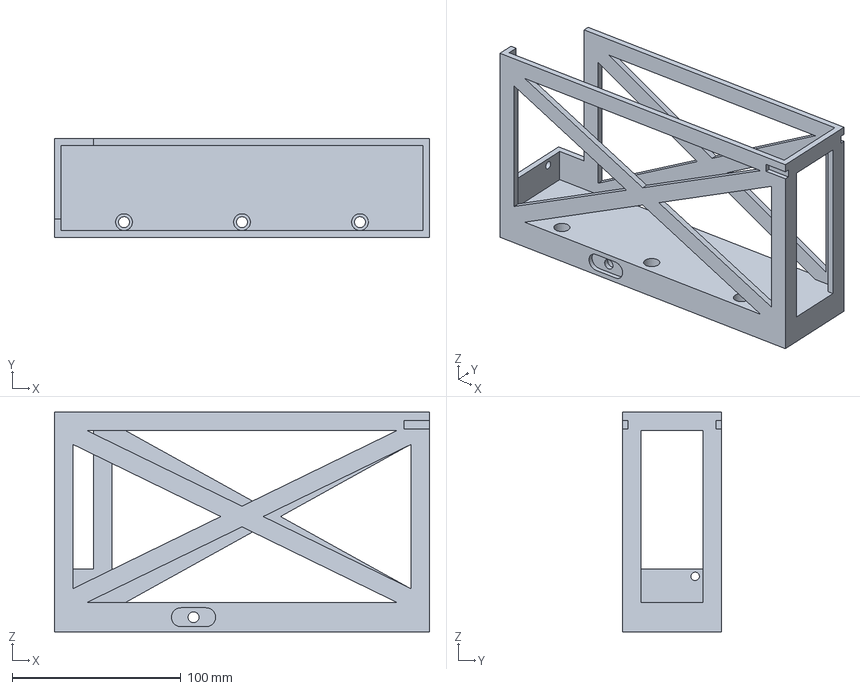
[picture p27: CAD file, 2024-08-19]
hw/case/Power Supply/Power Supply Case v11.3mf
222.5 x 58.5 x 130.5 mm

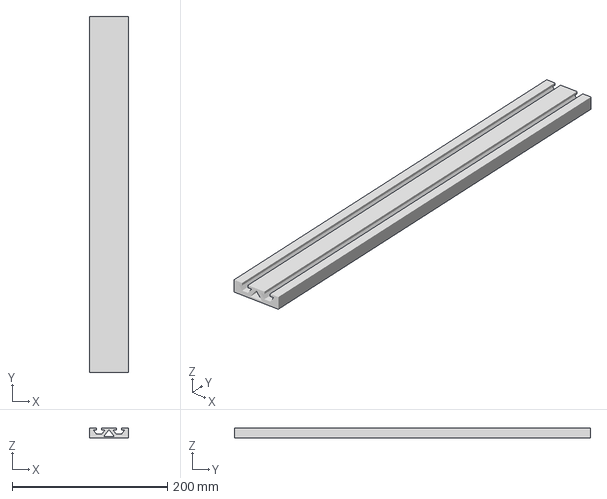
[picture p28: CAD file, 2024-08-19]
hw/case/10 Series/TS20-50-459 v8.3mf
50.8 x 459.0 x 12.7 mm

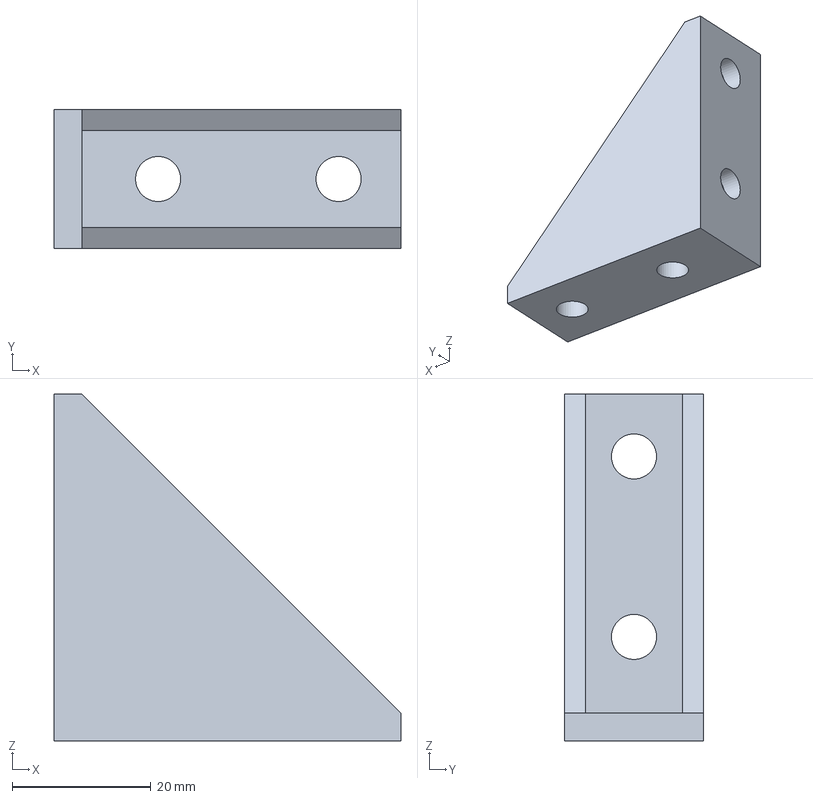
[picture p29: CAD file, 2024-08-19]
hw/case/Brackets/Small Bracket v3.3mf
50.0 x 20.0 x 50.0 mm

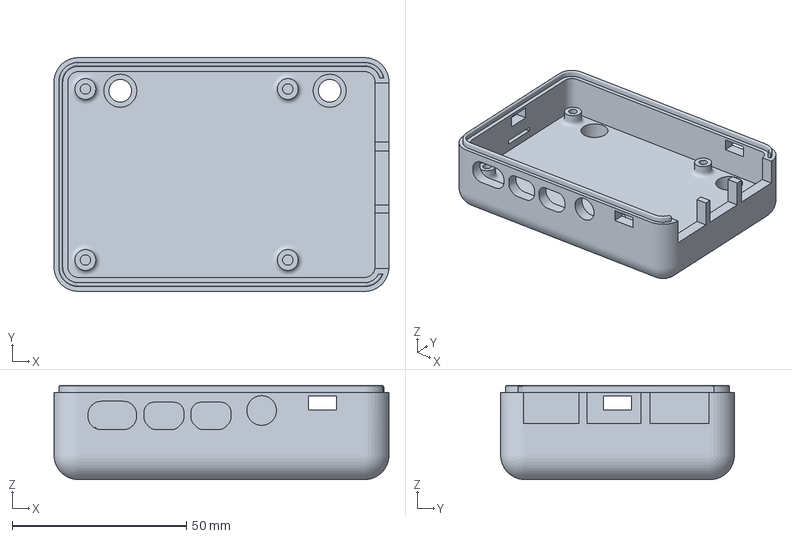
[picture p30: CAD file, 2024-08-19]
hw/case/Pi/BOTTOM BODY v6.3mf
96.0 x 67.0 x 27.0 mm

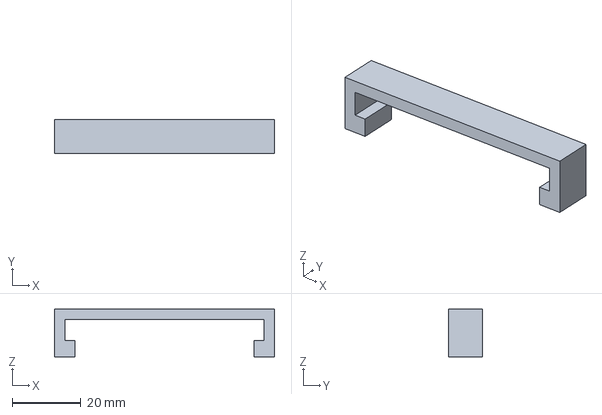
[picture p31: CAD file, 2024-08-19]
hw/case/Power Supply/Bracket v5.3mf
64.0 x 10.0 x 13.9 mm

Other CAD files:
docs/assets/feet-sss.3mf
hw/case/10 Series/TS20-50-635 v5.3mf
hw/case/10 Series/Frame Assembly v7.f3z
hw/case/Brackets/Big Bracket v3.3mf
hw/case/Brackets/Panel Holder 1 v4.3mf
hw/case/Brackets/Panel Holder 2 v2.3mf
hw/case/Brackets/Spacer 2 v6.3mf

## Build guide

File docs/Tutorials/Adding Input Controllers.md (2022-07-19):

# Adding Input Controllers

One of the central ideas of the SSS is that any demo can receive any type of input as long as it is formatted correctly. Adding an input to the SSS is not particularly difficult to do, but requires: 
1. The correct initialization of the input device/service in `__init__.py` in the `controllers` module
2. The actual driver file which contains the logic that forms the input and places it in the correct system queue (this will be it's own separate python file in the `controllers` directory).

## `controllers` module
Much like the `demos` module which contains all of the games and demos the SSS runs, the `controllers` module is the central location where all of the input devices/services pass information into the demo's `input_queue`. Just like a normal Python module, all of the initialization for this module takes place in the `__init__.py`. In the `controllers` module, the `__init__.py` is where all the controller services are initialized, checked for exceptions, and processed for the information to be put on the demos' `input_queue`.

### Initializing the input controller
In the `__init__.py` file, there is only one function: `start_inputs(system_queue, demo_input_queue)` which initializes all controllers and attaches them to the `system_queue` and the `demo_input_queue`. The beginning of this function is where we initialize the runner for our new input. We do this by declaring a variable and assigning it to the return value of our input driver's `start_processing_input()` function. In some cases, the initialization status of a controller will be provided from a different function (i.e. the keyboard driver for the simulator). Make sure you wrap the runner declaration inside of a `try/execpt` statement so if it fails, the entire SSS won't crash. In the case that the initialization runs into an exception, be sure to assign the runner to `None`. 

```python
try:
    from . import example  # This imports the actual input driver
    
    example_runner = example.start_processing_input(system_queue, demo_input_queue)
except Exception as e:
    example_runner = None
```

### Polling from the controllers
At the bottom of `start_inputs` is an infinite loop which will yields all of the inputs from each of the successfully initialized controllers into the appropriate system queues on every tick. To ensure that your controller has its inputs polled for every tick of the program, call `next()` on the generator declared:

```python
if example_runner:
    next(example_runner)
```

### The result
The following is a simplified result of what the `__init__.py` file should look like after having set up our `example` input. 
```python
from loguru import logger

def start_inputs(system_queue, demo_input_queue):
    try:
        logger.info("Loading my example input...")
        from . import example  # This imports the actual input driver

        example_runner = example.start_processing_input(system_queue, demo_input_queue)
        logger.info("...done")
    except Exception as e:
        example_runner = None
        logger.warning(e)
        logger.warning("Reason for input initialization failure will go here.")
        logger.warning("Program will continue to run without this input.")
    
    # More inputs are declared and initialized here

    while True:
        if example_runner:
            next(example_runner)

        # More input runners are `ticked` through here

        yield
```

## Input Driver File
The contents of your input driver file varies widely based on your method of generating input. The only requirement for each input driver file is a `start_processing_input(system_queue, demo_input_queue)` function which should contain a generator that will store input values in the correct queues before each `yield`. Depending on how your controlling service/device API works, you should return `None` from `start_processing_input`, throw an exception, or have a distinct function that checks initializability altogether in the case that it cannot start correctly.

### `example.py` Driver
Below is an arbitrary example skeleton file of what an input driver should contain. For more concrete examples, look at the the `mqtt` or `keyboard` drivers.

```python
# Example input driver file
from example_device import inputs

def start_processing_input(system_queue, demo_input_queue):
    while True:

        events = inputs.events.get()

        for event in inputs.events:
            # Check for KEYDOWN event and pass into input queue
            if event.type == inputs.KEYDOWN:

                if event.key == ESCAPE:
                    system_queue.put("QUIT")
                elif event.key == LEFT:
                    demo_input_queue.put("LEFT_P")
                
                # Continues for all key presses...

            # check for KEYUP event and pass into input queue
            elif event.type == inputs.KEYUP:
                if event.key == LEFT:
                    demo_input_queue.put("LEFT_R")
                elif event.key == UP:
                    demo_input_queue.put("UP_R")

                # Continues for all key releases...

            # Check for QUIT event.
            elif event.type == QUIT:
                system_queue.put("QUIT")

        inputs.update(events)

        yield

```

## Input Values

### Generally supported input values
For an input controller to be compatible with all of the demos in the SSS system, the following input messages need to be handled:

| Value | Description |
|---|---|
| LEFT_P | Left arrow pressed |
| LEFT_R | Left arrow released |
| RIGHT_P | Right arrow pressed |
| RIGHT_P | Right arrow released |
| UP_P | Up arrow pressed |
| UP_R | Up arrow released |
| DOWN_P | Down arrow pressed |
| DOWN_R | Down arrow released |
| START_P | Start button pressed |
| START_R | Start button released |
| SEL_P | Select button pressed |
| SEL_R | Select button released |
| PRI_P | Primary action button pressed |
| PRI_R | Primary action button released |
| SEC_P | Secondary action button pressed |
| SEC_R | Secondary action button released |

### Demo specific input values

As of the current version of the SSS, there is no system-wide mechanism for handling demo-specific input. However, the assumption could be made that if only the specific controller and demo could understand the type of messages sent on the `demo_input_queue` and therefore this would not affect normal operation. Yet, this is untested behavior and is done at the risk of that specific input driver's authors/users.

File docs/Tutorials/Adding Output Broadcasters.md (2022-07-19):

# Adding Output Broadcasters

One of the central ideas of the SSS is that any demo can transmit any type of output and  as long as it is formatted correctly. Handling output from the SSS is not particularly difficult to do, but requires: 
1. The correct initialization of the output device/service in `__init__.py` in the `broadcasters` module
2. The actual driver file which contains the logic to handle demo output by reading it in from the correct system queue (this will be it's own separate python file in the `broadcasters` directory).

## `broadcasters` module
Much like the `demos` module which contains all of the games and demos the SSS runs, the `broadcasters` module is the central location where all of the output devices/services receive information from the demo's `output_queue` and relay that to the appropriate broadcasters. Just like a normal Python module, all of the initialization for this module takes place in the `__init__.py`. In the `broadcasters` module, the `__init__.py` is where all the broadcasting services are initialized, checked for exceptions, and process the information from the demos' `output_queue`.

### Initializing the output broadcaster
In the `__init__.py` file, there is only one function: `start_outputs(system_queue, demo_output_queue)` which initializes all broadcasters and attaches them to the `system_queue` and the `demo_output_queue`. The beginning of this function is where we create a queue that will feed into output device. This is where the output of the `demo_output_queue` will eventually go. We then initialize the runner for our output device/service by declaring a variable and assigning it to the return value of our output driver's `start_processing_output()` function. In some cases, the initialization status of a broadcaster may be provided by a different function. Make sure you wrap the runner declaration inside of a `try/execpt` statement so if it fails, the entire SSS won't crash. In the case that the initialization runs into an exception, be sure to assign the runner to `None`. 

```python
try:
    from . import example  # This imports the actual output driver

    example_q = Queue()
    
    example_runner = example.start_processing_output(system_queue, example_q)
except Exception as e:
    example_runner = None
```

### Polling from `demo_output_queue`
At the bottom of `start_outputs` is an infinite loop which extracts the current values on the `demo_output_queue` and passes them to available broadcaster runners. To ensure that your broadcaster receives its outputs from the output queue for every tick of the program, make sure `next()` is called on the runner:

```python

# Loops through every available output message in the output queue
for payload in utils.get_all_from_queue(demo_output_queue):

    # If broadcaster is successfully initialized, the output will go to the service/device's queue and into the driver
    if example_runner:
        example_q.put(payload)
        next(example_runner)
```

### The result
The following is a simplified result of what the `__init__.py` file should look like after having set up our `example` output. 
```python
from queue import Queue

from loguru import logger

from . import utils

def start_outputs(system_queue, demo_output_queue):
    try:
        logger.info("Loading example output...")
        from . import example

        example_q = Queue()

        example_runner = example.start_processing_output(system_queue, example_q)
        logger.info("...done")
    except Exception as e:
        example_runner = None
        logger.warning(e)
        logger.warning("Reason for broadcaster initialization failure will go here.")
        logger.warning("Program will continue to run without this output.")

    # More broadcasters are declared and initialized here

    while True:

        for payload in utils.get_all_from_queue(demo_output_queue):
            if example_runner:
                example_q.put(payload)
                next(example_runner)

            # More output runners are `ticked` through here

        yield
```

## Output Driver File
The contents of your output driver file varies widely based on the device or service's method of receiving input. The only requirement for each output driver file is a `start_processing_output(system_queue, driver_q)` function which should contain a generator that will read demo output values from the queue created for the driver before each `yield`. Depending on how your broadcasting service/device API works, you should return `None` from `start_processing_output`, throw an exception, or have a distinct function that checks initializability altogether in the case that it cannot start correctly.

### `example.py` Driver
Below is an arbitrary example skeleton file of what an output driver could look like. For a more concrete example, look at the the `mqtt` driver.

```python
# Example output driver file
from example_device import process_data

from . import utils

def start_processing_output(system_queue, example_q):
    
    while True:

        for item in utils.get_all_from_queue(example_q):
            process_data(item)
        yield

```

## Output Values
Unlike `demo_input_queue` values, there are no set of universally supported output types for the SSS. It is understood that each type of output that gets put on the `demo_output_queue` will vary widely depending on that demo's targeted broadcaster and purpose. However, it is recommended that info that is sent on the output queue be formatted in JSON.

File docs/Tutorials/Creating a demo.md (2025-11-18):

# Creating a demo

At its core, using the SSS is meant to be a learning experience. Anyone who wants to know more about computer engineering and the Internet of Things can go through the demos and learn quite a bit by experiencing the end result. However, the SSS is also designed to be an educational tool for designers. Anyone with the desire can make a demo themselves without needing to understand the entire system! In this article, we will discuss the template for making one of these demos by looking at the template’s basic structure and its required subcomponents.

## Template Format

All of the demos for the SSS are located in the `demos` folder in the `seven_segment_sign` repo that you clone from GitHub. If you take a look at the contents of `demos`, you’ll notice that each demo has its own folder with a `main.py` file inside of it:

```bash
demos
├── breakout
│   ├── high_score.txt
│   └── main.py
├── breakout_ai
│   └── main.py
├── checkerboard
│   └── main.py

.... 
```

Notice that all of the folder names are **lowercase** and that all of the programs are named **main.py**. If you don’t follow this convention, the system won’t see your demo and it will fail to load when you run the program. 

But what goes inside of your `main.py` is what really counts. The following format must be observed for your demo to run correctly. If you want to use this example as a boilerplate to get you started, you can always copy it from `demos/template/main.py`. 

```python
class Template:
    """This is a boilerplate class for creating new demos/games for the SSS platform. It needs to include definitions for the following functions: init, run, stop.
    The init function needs to at least have the things shown below. Frame rate is in frames per second and demo time is in seconds. Demo time should be None if it is a game.
    The run function yields a generator. This generator will be called a specified frame rate, this controls what is being pushed to the screen.
    The stop function is called when the demo/game is being exited by the upper SSS software. It should reset the state for the game"""

    # User input is passed through input_queue
    # Game output is passed through output_queue
    # Screen updates are done through the screen object
    def __init__(self, input_queue, output_queue, screen):
        # Provide the framerate in frames/seconds and the amount of time of the demo in seconds
        self.frame_rate = 10
        self.demo_time = 300  # None for a game

        self.input_queue = input_queue
        self.output_queue = output_queue
        self.screen = screen
        # init demo/game specific variables here

    def run(self):
        # Create generator here
        while True:
            self.screen.draw_text(self.screen.width // 2 - 5, self.screen.height // 2 - 4, "HELLO THERE", push=True)
            yield

    def stop(self):
        # Reset the state of the demo if needed, else leave blank
        pass
```

When creating your class object, name sure that the first letter of its name is capitalized. If you have a demo with two words (i.e. `breakout_ai`) make sure you capitalize the first letter of every word (i.e. `Breakout_Ai`). Failure to do this will cause your demo to not load or execute properly into the SSS system. You’ll also notice that apart from the normal Python `__init__()` method for a class, there is also a `run()` , `stop()` , and `get_input_buff()`. Implementing these functions is crucial to making sure that your demo will execute correctly at runtime. An explanation of what each one does is included below. 

## `__init__()`

This function allows you to set up some initial values for your demo. For example, if you were creating a game and wanted to include the initial amount of lives or the amount of ammo in a shooter, `__init__()` is the perfect place to set that up! Apart demo-specific variables that could be initialized, there are also a few SSS specific variables which must also be initialized which will affect how your demo runs and interacts with the rest of the system.

### frame_rate

This variable determines how fast your demo runs (i.e how many frames are rendered in a second). If your game is intended to have a buttery experience higher values will be more suited to your needs. 

***NOTE:** setting the `frame_rate` too high can result in too quick of a game on the simulator or undefined behavior on the actual SSS due to hardware limitations.* 

### demo_time

If you are creating a non-interactive demo (i.e. a shape bouncing around the screen or some other concept that does not require input), you will need to set a demo_time. This value will determine how long your demo will run for when the SSS is in kiosk/screensaver mode (i.e. cycling through demos when no one is actively using it). If you are planning on developing an interactive demo/game, set this value to `None`.

### input_queue

If you are creating a demo which requires active user input, you will need to keep track of the values are are coming in through the input queue. Regardless of what controller is connected to the SSS, the supported inputs are:

| Value | Description |
|---|---|
| LEFT_P | Left arrow pressed |
| LEFT_R | Left arrow released |
| RIGHT_P | Right arrow pressed |
| RIGHT_R | Right arrow released |
| UP_P | Up arrow pressed |
| UP_R | Up arrow released |
| DOWN_P | Down arrow pressed |
| DOWN_R | Down arrow released |
| START_P | Start button pressed |
| START_R | Start button released |
| SEL_P | Select button pressed |
| SEL_R | Select button released |
| PRI_P | Primary action button pressed |
| PRI_R | Primary action button released |
| SEC_P | Secondary action button pressed |
| SEC_R | Secondary action button released |

By setting `self.input_queue = input_queue` you link the input_queue for your demo to the system’s input buffer. All input information can be retrieved directly through this object or by using the `get_input_buff()` function as explained below. 

***NOTE:** This object is a Python Queue object. Any functions found [here](https://docs.python.org/3/library/queue.html) can be used on this object.*

### output_queue

If your demo needs to communicate information that will not be seen on the screen back to the user (i.e. a score or number of lives), this can be accomplished by using the output_queue. You can link your demo’s output_queue to the system output_queue by using `self.output_queue = output_queue`. At the current moment there are a limited amount of topics that you can send output through:

| Value | Description |
|---|---|
| SCORE | Sets the score of a game. |
| LIVES | Keeps track of the amount lives of a player |

To send data through one of these channels, you will `put` the name of the topic and the value you wish to send:

```python
self.output_queue.put("SCORE " + str(self.score))
```

***NOTE:** This object is a Python Queue object. Any functions found [here](https://docs.python.org/3/library/queue.html) can be used on this object.*

### screen

This object controls what will be drawn on the screen. Any functions as described in this [API doc](Game%20Display%20(Graphics%20functions).md) will work on this screen object. The demo screen is connected to the SSS system screen as follows:

```python
self.screen = screen
```

## `run()`

This function is what causes your actual program to run. Everything inside of this demo will be executed at runtime. Notice that in our boilerplate we surround the contents of this function with a `while True` loop ending with a `yield`. This special organization will cause whatever is inside the loop to be repeated until the system indicates that it is time for your demo to stop. By placing a `yield` keyword at the end of the loop, this converts the function from a **blocking** function to a **non-blocking** function (for the purposes of the system). If `yield` is not provided at the end of a frame rendering, the program will have no way to release control back to the SSS to actually draw anything or process any inputs and outputs that the demo. For a simple example of how a demo works with this non-blocking functionality, take a look at the `template` demo. For more complex examples, demos such as `game_of_life` , `snake`, or `breakout` which include multiple `yield`s for multiple cases.

## `stop()`

Code in this function will be exited right as soon as your demo is ended by the SSS or user. If you need to reset state or do any sort of cleanup, that code belongs here. If there is nothing fancy like that in your demo, no worries! Just leave a `pass` and be on your merry way.

## Handling Input in Your Demo

Most games on the SSS are pretty simple and are only meant to handle one keypress at a time. However, if you are feeling ambitious and want to keep track of multiple keypresses at a time (i.e. holding up and left to jump diagonally), this function will help you catch that by returning all keypresses waiting in the queue as a list. Below is a snippet from `breakout` which illustrates this functionality:

```python
# Include this at the top of your demo
from demos.utils import get_all_from_queue

# Put this part in your while True loop 
for keypress in get_all_from_queue(self.input_queue):

    if keypress == "LEFT_P":
        # Some action
        pass
    if keypress == "LEFT_R":
        # Some action
        pass
    if keypress == "RIGHT_P":
        # Some action
        pass
    if keypress == "RIGHT_R":
        # Some action
        pass 
```

## Conclusion

By following the `template` format, you learn about and are accountable for most of the key components of a demo! If you are still feeling overwhelmed and don’t know where to start in your demo creation journey, take a look at some of the existing ones and try to modify them bit by bit, taking note of what changes you caused. If there are any clarifications that need to be made, please feel free to reach out by [opening an issue on the GitHub repo](https://github.com/NET-BYU/seven_segment_sign/issues/new) or taking a look at how to get [support](../Troubleshooting/Support.md) so we can help you and also update our docs. We’re excited to see what you create!

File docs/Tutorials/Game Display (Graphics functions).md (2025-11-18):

# Game Display

Many of the following functions have parameters called combine and push. Push is inherently set to False. If it is set to True then all of the recent game display function calls will be written to the screen. Combine is inherently set to True. Each of the the individual seven segment digits are broken up into two separate digits. When writing to one of the pixels of a digit, combine states that you want to keep what is in the other pixel of the digit. When set to false it will erase whatever is on the other side of the digit. This is a quirk of making pixels out of seven segment digits.

Many of the below functions also take an x and y parameters. These are self explanatory. They are the x, y coordinates of where you want to start to draw. The origin is on the top left of the screen. A game_display object has a width and height class member that can be accessed and encouraged to be used.

---

### **init**

The init function has three parameters: board_objects, width, and height. The later two are easier to explain. The width and height are for how many pixels the display is across. A seven segment display digit is broken up into 1 pixel across and 2 pixels down, where the two pixels down share the middle line. Lets say you have 8 seven segment digits across you would put 8 for width and 2 for height. The last parameter is the board_objects. This parameter needs to be a 2d list of panel objects in the order they are on the sign. The hardware is broken up into 3 panels across and 4 panels down. Each panel has 16 columns and 6 rows of digits. An example of what would be passed into this is [[panel0, panel1, panel2],[panel3, panel4, panel5],[panel6, panel7, panel8],[panel9, panel10, panel11]]. For the physical hardware, the panel class is called SevenSegnment, which can be found under display/seven_seg.py. The simulator panel class is called Panel and is found under simulator/simulator.py. 

### draw_pixel

This function call is the simplest out of all of them. It will draw an individual pixel to the screen. A pixel is defined by the four sides of either the top or bottom of the individual digit.. The value parameters of this function determines which of those four sides is turned on. It is controlled by a nibble of data (4 bits). Pass a 1 for the bottom, 2 for the left, 4 for the top, 8 for the right, and any combination thereof.

<script src="https://ajax.googleapis.com/ajax/libs/jquery/1.7.1/jquery.min.js" type="text/javascript"></script>
<script>
    var a = false;
    var b = false;
    var c = false;
    var d = false;
    var canvas;
    var context;
    $(document).ready(function () {
        canvas = $("#canvas")[0];
        context = canvas.getContext("2d");
        regularpolygon(context, 0, false);
        regularpolygon(context, 2, false);
        regularpolygon(context, 1, false);
        regularpolygon(context, 3, false);
    });
    function regularpolygon(ctx, pos, fill) {
        ctx.font = "30px Arial";

        switch (pos) {
            case 0:
                c = fill;
                ctx.beginPath();
                ctx.moveTo(75, 50);
                ctx.lineTo(175, 50);
                ctx.lineTo(200, 75);
                ctx.lineTo(175, 100);
                ctx.lineTo(75, 100);
                ctx.lineTo(50, 75);
                ctx.lineTo(75, 50);
                ctx.closePath();
                if (fill == true) {
                    ctx.fillStyle = '#f00';
                    ctx.fill();
                    ctx.fillStyle = '#fff';

                }
                else {
                    ctx.fillStyle = '#fff';
                    ctx.fill();
                    ctx.fillStyle = '#f00';
                }
                context.fillText("c", 115, 83);
                ctx.stroke();
                break;
            case 1:
                b = fill;
                ctx.beginPath();
                ctx.moveTo(45, 80);
                ctx.lineTo(70, 105);
                ctx.lineTo(60, 205);
                ctx.lineTo(35, 230);
                ctx.lineTo(10, 205);
                ctx.lineTo(20, 105);
                ctx.lineTo(45, 80);
                ctx.closePath();
                if (fill == true) {
                    ctx.fillStyle = '#f00';
                    ctx.fill();
                    ctx.fillStyle = '#fff';

                }
                else {
                    ctx.fillStyle = '#fff';
                    ctx.fill();
                    ctx.fillStyle = '#f00';
                }
                context.fillText("b", 30, 160);
                ctx.stroke();
                break;
            case 2:
                a = fill;
                ctx.beginPath();
                ctx.moveTo(65, 210);
                ctx.lineTo(165, 210);
                ctx.lineTo(190, 235);
                ctx.lineTo(165, 260);
                ctx.lineTo(65, 260);
                ctx.lineTo(40, 235);
                ctx.lineTo(65, 210);
                ctx.closePath();
                if (fill == true) {
                    ctx.fillStyle = '#f00';
                    ctx.fill();
                    ctx.fillStyle = '#fff';

                }
                else {
                    ctx.fillStyle = '#fff';
                    ctx.fill();
                    ctx.fillStyle = '#f00';
                }
                context.fillText("a", 105, 243);
                ctx.stroke();
                break;
            case 3:
                d = fill;
                ctx.beginPath();
                ctx.moveTo(205, 80);
                ctx.lineTo(230, 105);
                ctx.lineTo(220, 205);
                ctx.lineTo(195, 230);
                ctx.lineTo(170, 205);
                ctx.lineTo(180, 105);
                ctx.lineTo(205, 80);
                ctx.closePath();
                if (fill == true) {
                    ctx.fillStyle = '#f00';
                    ctx.fill();
                    ctx.fillStyle = '#fff';

                }
                else {
                    ctx.fillStyle = '#fff';
                    ctx.fill();
                    ctx.fillStyle = '#f00';
                }
                context.fillText("d", 190, 160);
                ctx.stroke();
                break;
        }

        let val = 0;
        if (a) {
            val = val + 1
        }
        if (b) {
            val = val + 2
        }
        if (c) {
            val = val + 4
        }
        if (d) {
            val = val + 8
        }
        document.getElementById('hexval').textContent = "0x" + val.toString(16);
    }

    // function updatepixel(texval)
    // {
    //     if(texval)
    // }

</script>

<div>
    <canvas id="canvas" width="500" height="300">OOPS.. Upgrade your Browser</canvas>
</div>
<h2>Use the buttons to configure the pixel!</h2>

<button onclick="regularpolygon(context, 2, !a)">a</button>
<button onclick="regularpolygon(context, 1, !b)">b</button>
<button onclick="regularpolygon(context, 0, !c)">c</button>
<button onclick="regularpolygon(context, 3, !d)">d</button>

### draw_hline

This function simply draws a horizontal line on the screen. It starts at the given x and y value and goes the provided length. The top parameter is set to True by default meaning the horizontal line will be drawn on the top of the pixel. When set to false it will drawn on the bottom of the pixel. This function draws from the left to the right on the screen.

### draw_vline

This function simply draws a vertical line on the screen. It starts at the given x and y value and goes the provide length. The left parameter is set to True by default meaning the vertical line will be drawn on the left side of the pixel. When set to false it will be drawn on the right of the pixel. This function draws from the top to the bottom on the screen.

### draw_shape_line

This function is a can draw an arbitrary pixel design in a line. This line can be diagonal even. It has the additional end_x and end_y parameters.

### draw_text

This function can draw a text string to the display. It can even split between two vertically aligned digits. It is hard to see what the text is at that point but it is a possibility. The display/symbols.py file provides a list of almost 90 different ASCII characters that can be drawn on the screen. Many of the characters are an approximation and may not look the way you are expecting it to look. Since this function can draw on split functions this function can not be called lower than the screen pixel height  - 2.

### get_pixel

This is a specialty function call that can return what is supposed to be displayed at a given x and y value

### push

When you call many of the above functions it will not immediately write the graphic to the screen. It is put into a buffer to be processed all at once. The push function is the function that actually pushes the changes to the screen. It is more efficient to write to the screen in this manner.

### clear

This function will clear the display buffer and the graphics on the screen. It is slow and many artifacts can be seen if it is called over and over. It generally should only be called when a game is starting or ending and the entire screen needs to be cleared off.

---

These are the base functions that we felt were needed to do almost everything we needed for the demos. Feel free to add more functions. Make sure to thoroughly test it on many edge cases.

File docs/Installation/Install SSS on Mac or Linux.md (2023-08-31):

## Checking Dependencies

To install the SSS on your Mac or Linux device, you will need some certain dependencies. You can get them from your package manager by doing the following

>This project only uses `python3`. Check to see if you are using `python3` by:
```bash
python -V
```
If your system has multiple versions of `python` installed, you can force v3 by replacing all `python` and `pip` commands with `python3` and `pip3`.

### For Mac
Make sure that you have [homebrew](https://brew.sh/) installed and then run the following:
```bash
curl https://bootstrap.pypa.io/get-pip.py | python && brew install git virtualenv
```

### For Linux
If you are using [Ubuntu](https://ubuntu.com/) or any other [Debian](https://debian.org) based Linux distro with the `apt` package manager:
```bash
sudo apt install git python3-virtualenv
```
If you are using [RedHat](https://redhat.com/) or any of its variants that uses `dnf`:
```bash
sudo dnf install git python-virtualenv
```

## Setting up SSS
Once you have all the dependencies for your system installed, you can now move onto downloading and setting up the SSS on your system. The following steps should be system-agnostic.

First we'll get the code from GitHub by cloning the repository:

```bash
git clone https://github.com/NET-BYU/sss.git
```

Now we'll move into the folder and make sure our virtual environment is set up:

```bash
cd sss                      # Change to SSS project directory
virtualenv venv             # Create a python virtual environment called venv
source venv/bin/activate    # Activate the venv environment
```
You can now verify that you are inside a virtual environment by `echo`ing out the `VIRTUAL_ENV` variable

```bash
echo $VIRTUAL_ENV
```
If the `VIRTUAL_ENV` is set (i.e. you get output from the previous command like `/home/christopolise/dev/sss/venv`), this indicates that you are inside your new Python virtual environment.

>Most shells will visually indicate that you are inside of a virtual environment by changing the prompt. For example, you are using `bash`, your prompt change from `user@computer1$` to `(venv) user@computer1$`. You should notice the prompt of your terminal change to indicate that you are now in your newly created python virtual environment. All of the following steps assume you are within this environment. If you are not, you will install all SSS dependencies system-wide which may conflict with some previous configurations.

Then you will need to install all the python requirements for the SSS:

```bash
python3 -m pip install -r requirements.txt
```

And that's it! Once this has successfully completed, you are ready to run the simulator and start developing for the SSS! For more information, go to [Get Started](../Overview/Get%20started.md).

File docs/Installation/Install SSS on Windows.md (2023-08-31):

## Checking Dependencies

To install the SSS on your Windows device, you will need some certain dependencies. You can get them from your package manager by doing the following

You will need to install [Python 3](https://www.python.org/downloads/release/python-3106/) on your computer if you don't have it installed already.

You will also need a `git` on your machine and some way to interface with it. We recommend [Git Bash](https://gitforwindows.org/).

Once that is succesfully set up, you will need to make sure that `pip` is installed on your machine as well. Enter the following in your cmd:

```cmd
curl https://bootstrap.pypa.io/get-pip.py -o get-pip.py
python get-pip.py
```

With `pip` installed we can now install `virtualenv`:
```cmd
python3 -m pip install --user virtualenv
```

## Setting up SSS
Once you have all the dependencies for your system installed, you can now move onto downloading and setting up the SSS on your system. 

First we'll get the code from GitHub by cloning the repository. Open up your Git Bash program and make sure that you are in your desired folder for downloading. Then clone the repo:

```bash
git clone https://github.com/NET-BYU/sss.git
```

Now with cmd, go to the folder where you cloned the repo.

```cmd
cd <path\ to\ repo>\sss     :: Change to SSS project directory
```

Then we will make sure that we create a virtual environment for all the python dependencies

```cmd
python -m venv venv         :: Create a python virtual environment called venv
.\venv\Scripts\activate     :: Activate the venv environment
```

>You should notice the prompt of your terminal change to indicate that you are now in your newly created python virtual environment. All of the following steps assume you are within this environment. If you are not, you will install all SSS dependencies system-wide which may conflict with some previous configurations.

Then you will need to install all the python requirements for the SSS:

```bash
pip install -r requirements.txt
```

And that's it! Once this has successfully completed, you are ready to run the simulator and start developing for the SSS! For more information, go to [Get Started](../Overview/Get%20started.md).

## Running on Windows
It its current state, the SSS cannot autoload all of the demos in kiosk, testing, and simulator mode. This may be fixed in a future release.

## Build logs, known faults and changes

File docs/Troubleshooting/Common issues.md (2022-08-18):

## General SSS FAQ

<details>
  <summary>Errors stating that there isn't a specific Python module installed when it is</summary>
  <br>
  After the initial installation and running of the program, users may find that upon returning to run the program again, they are met with errors that state they do not have the right Python Modules installed. There are several reasons that could cause this:

  <br>
  <h3>Not using the venv for SSS</h3>
  Make sure that you are running the SSS inside the virtual environment by running:

  ```bash
  which python
  ```

  If the response string does not indicate that the python interpreter is coming from a virtual environment, for example:

  ```
  /usr/bin/python
  ```

  Then make sure to activate the virtual environment created for the SSS:

  ```bash
  source ~/sss/venv/bin/activate        # Make sure this is the path to your venv
  ```

  Then check the python interpreter being used again. It should look something like the following:
  
  ```bash
  which python

  ./venv/bin/python
  ```

  <h3>Installed python modules in wrong environment</h3>
  During the setup process of the SSS, it is possible that you may not have entered into the virtual environment made for the project before installing the dependencies found in requirements.txt. To see if these modules exist in your virtual environment:

  First activate the created environment:
  ```bash
  source ~/sss/venv/bin/activate        # Make sure this is the path to your venv
  ``` 

  Check the list of installed modules in the venv:
  ```bash
  pip freeze                            # Shows list of python modules installed in venv
  ```

  If the list of packages printed includes the dependencies found in requirements.txt, then you should be good and a further issue should be opened on the repository.
  <br><br>

</details>

## Physical SSS FAQ

<details>
  <summary>There is no drawing on the screen even though there is terminal output</summary>
  
<br>
  If there is no drawing on the screen but the terminal output from the program indicates no errors, this indicates that there is something wrong with the hardware itself. There are several things you can check to rule out serious damage first:

  <ol>
    <li>Make sure the screen is plugged in. Often times this is the most overlooked problem</li>
    <li>Restart the SSS hardware. Unplug everything from the wall. Plug in the Raspberry Pi. Log into the Pi's OS. Plug in the screen hardware. Doing the preceding in this order allows the SSS program to detect the ICs in the screen in a determined (uninitialized) state. </li>
    <li>Check the continuity of the traces between joints in any of the circuits that carry power. </li>
  </ol>
  <br><br>
</details>

<details>
  <summary>I plugged in the screen but it is flashing red, random patterns. What do I do?</summary>
  
<br>
  Normally if the screen is flashing red sporadically, this is indicative of the ICs on the screen being in an uncertain state. The best thing to do is the following:

  <ol>
    <li>Unplug everything from the wall.</li>
    <li>Plug in the Raspberry Pi. </li>
    <li>Log into the Pi's OS. </li>
    <li>Plug in the screen hardware.</li>
  </ol>

   Doing the preceding in this order allows the ICs to be reset from their undetermined state. 
  <br><br>
</details>

<details>
  <summary>Why are there random artifacts left on the screen as a demo is running?</summary>
  <br>
  If a demo is executing normally, but then random digits on the SSS start to display unexpected patterns, this is most likely due to the refresh rate of the ICs being too high. Because the traces and wires on the SSS are somewhat long, this means that the signal is more susceptible to delay and noise. The faster the ICs try to refresh at, the more likely it is for the data to miss the SCLK rising window.
<br>
  To mititgate this issue, we will need to modify the seven_seg.py file in the display directory. To edit the file use your favorite text editor and open up the sss/display/seven_seg.py file. Then we will need to modify the following line:
<br>
  ```python
  DEFAULT_BAUDRATE = 3000000            # Refresh rate of the ICs is currently set to 3MHz
  ```
  Dropping the DEFAULT_BAUDRATE value is a quick way to clear up artifacts. However, this also comes with the unfortunate side effect of slowing the execution of the SSS down. A more sure-fire way to fix this problem would be to redesign the panels of the screen to minimize the length of the traces and also make the width thicker. Furthermore, a more concerted effort to reduce noise in the overall design would more effectivly mitigate signal corruption.
  <br><br>
</details>

## Simulator SSS FAQ
<details>
  <summary>None of my outputs seem to work with the simulator.</summary>
  <br>
  As of this revision of the SSS, no output handling has been implemented for the simulator, although it is definitely a TODO.
  <br><br>
</details>

If there are any other questions that you have concerning the use of the SSS project, please feel free to go to the [support](Support.md) page and follow the links to open an issue.

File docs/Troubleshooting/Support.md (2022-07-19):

# Support

As of the latest release, the SSS has been solely developed by students inside of the [BYU NET Lab](https://netlab.byu.edu) and participants in the BYU ECEN IMMERSE 2022 program. While we might not have the exact same group to maintain the demos they made over the summer, the current group of students in the lab frequently monitor the [issues](https://www.github.com/NET-BYU/sss/issues) and [pull requests](https://www.github.com/NET-BYU/sss/pulls) on the repository.

Please feel free to open either and [issue](https://www.github.com/NET-BYU/sss/issues) or [pull request](https://www.github.com/NET-BYU/sss/pulls) at any time!

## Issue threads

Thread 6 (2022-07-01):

Display is not re-initialized when user is switching between demos

philipbl, 2022-07-01:
This is a problem with kiosk mode.

Closed 2022-07-05.

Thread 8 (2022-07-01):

Change "video" files from CSV to NPY

christopolise, 2022-07-01:
As mentioned in an earlier pull request for the `video` module, using CSVs to contain all of the pixel values for videos can get really big really quick because ASCII vals are much bigger than binary vals. Since the demo uses `numpy` to process frames, we could use `.npy` binary files instead as seen in the `sound_visualizer` demo. @apal6981 has some experience with this and might be able to help.

christopolise, 2023-08-31:
Resolved in #44

Closed 2023-08-31.

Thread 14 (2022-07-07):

Stop demo on exit

christopolise, 2022-07-07:
I am writing a demo that messes with memory management (in Python? The horror!). Everything is tied up nicely but I notice that the runners do not call stop on the current running demo before exiting.

Fixing this in the simulator is easy enough (there is just one line to add before `sys.exit()`), but I feel like it might be a little more tricky for `kiosk` and `demo` when they are not running with the `-s` flag.

philipbl, 2022-07-08:
@christopolise, we do call `stop()` in the runners:

https://github.com/NET-BYU/sss/blob/412d4529087c569887620513b8fb25227e620b4e/runners/demo.py#L63

https://github.com/NET-BYU/sss/blob/412d4529087c569887620513b8fb25227e620b4e/runners/kiosk.py#L117

https://github.com/NET-BYU/sss/blob/412d4529087c569887620513b8fb25227e620b4e/runners/kiosk.py#L141

https://github.com/NET-BYU/sss/blob/412d4529087c569887620513b8fb25227e620b4e/runners/kiosk.py#L151

https://github.com/NET-BYU/sss/blob/412d4529087c569887620513b8fb25227e620b4e/runners/simulator.py#L102

https://github.com/NET-BYU/sss/blob/412d4529087c569887620513b8fb25227e620b4e/runners/test.py#L35

Maybe I am misunderstanding the problem?

christopolise, 2022-07-08:
I don't think I framed it the best. When exiting the simulator in `pygame`, regardless of where the demo is in its execution or where the runner is, when the signal to kill the program is called, a function (I believe) is called before exit. I don't know if the other runners have a function like that to catch a sigterm and run a demo.stop() type call on it...

philipbl, 2022-07-08:
That makes sense. I will start working on that.

Closed 2022-07-28.

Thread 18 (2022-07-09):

Controller issue with Doom

christopolise, 2022-07-09:
Keys are a little sticky. There are times/button press combos that cause the release signal not to be registered and for a key to stay pressed. Look into using SYSV message queues rather than shared memory.

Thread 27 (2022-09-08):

Snake corner case

christopolise, 2022-09-08:
This seems to be a very rare error that happens when there are no possible paths for the snake to take. This is the stack trace:

```
  run_loop(screen)
File "/home/pi/sss/runners/kiosk.py", line 194, in run_loop
  current_demo, handle_input, queues, screen, demo_time_override
File "/home/pi/sss/runners/kiosk.py", line 136, in play_demo_from_idle
  next(runner)
File "/home/pi/sss/demos/snake_ai/main.py", line 126, in run
  current_location = snek_path.pop(0)
IndexError: pop from empty list
```
A workaround has been fixed in PR #26, but a more permanent solution should be used

philipbl, 2024-10-24:
Fixed in #69

Closed 2024-10-24.

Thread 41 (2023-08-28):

Raspberry Pi for testing down

christopolise, 2023-08-28:
Since we cannot run the tests on the Raspberry Pi, any builds up to this point will timeout or fail.

philipbl, 2024-10-23:
This was solved by @christopolise. Thanks!

Closed 2024-10-23.

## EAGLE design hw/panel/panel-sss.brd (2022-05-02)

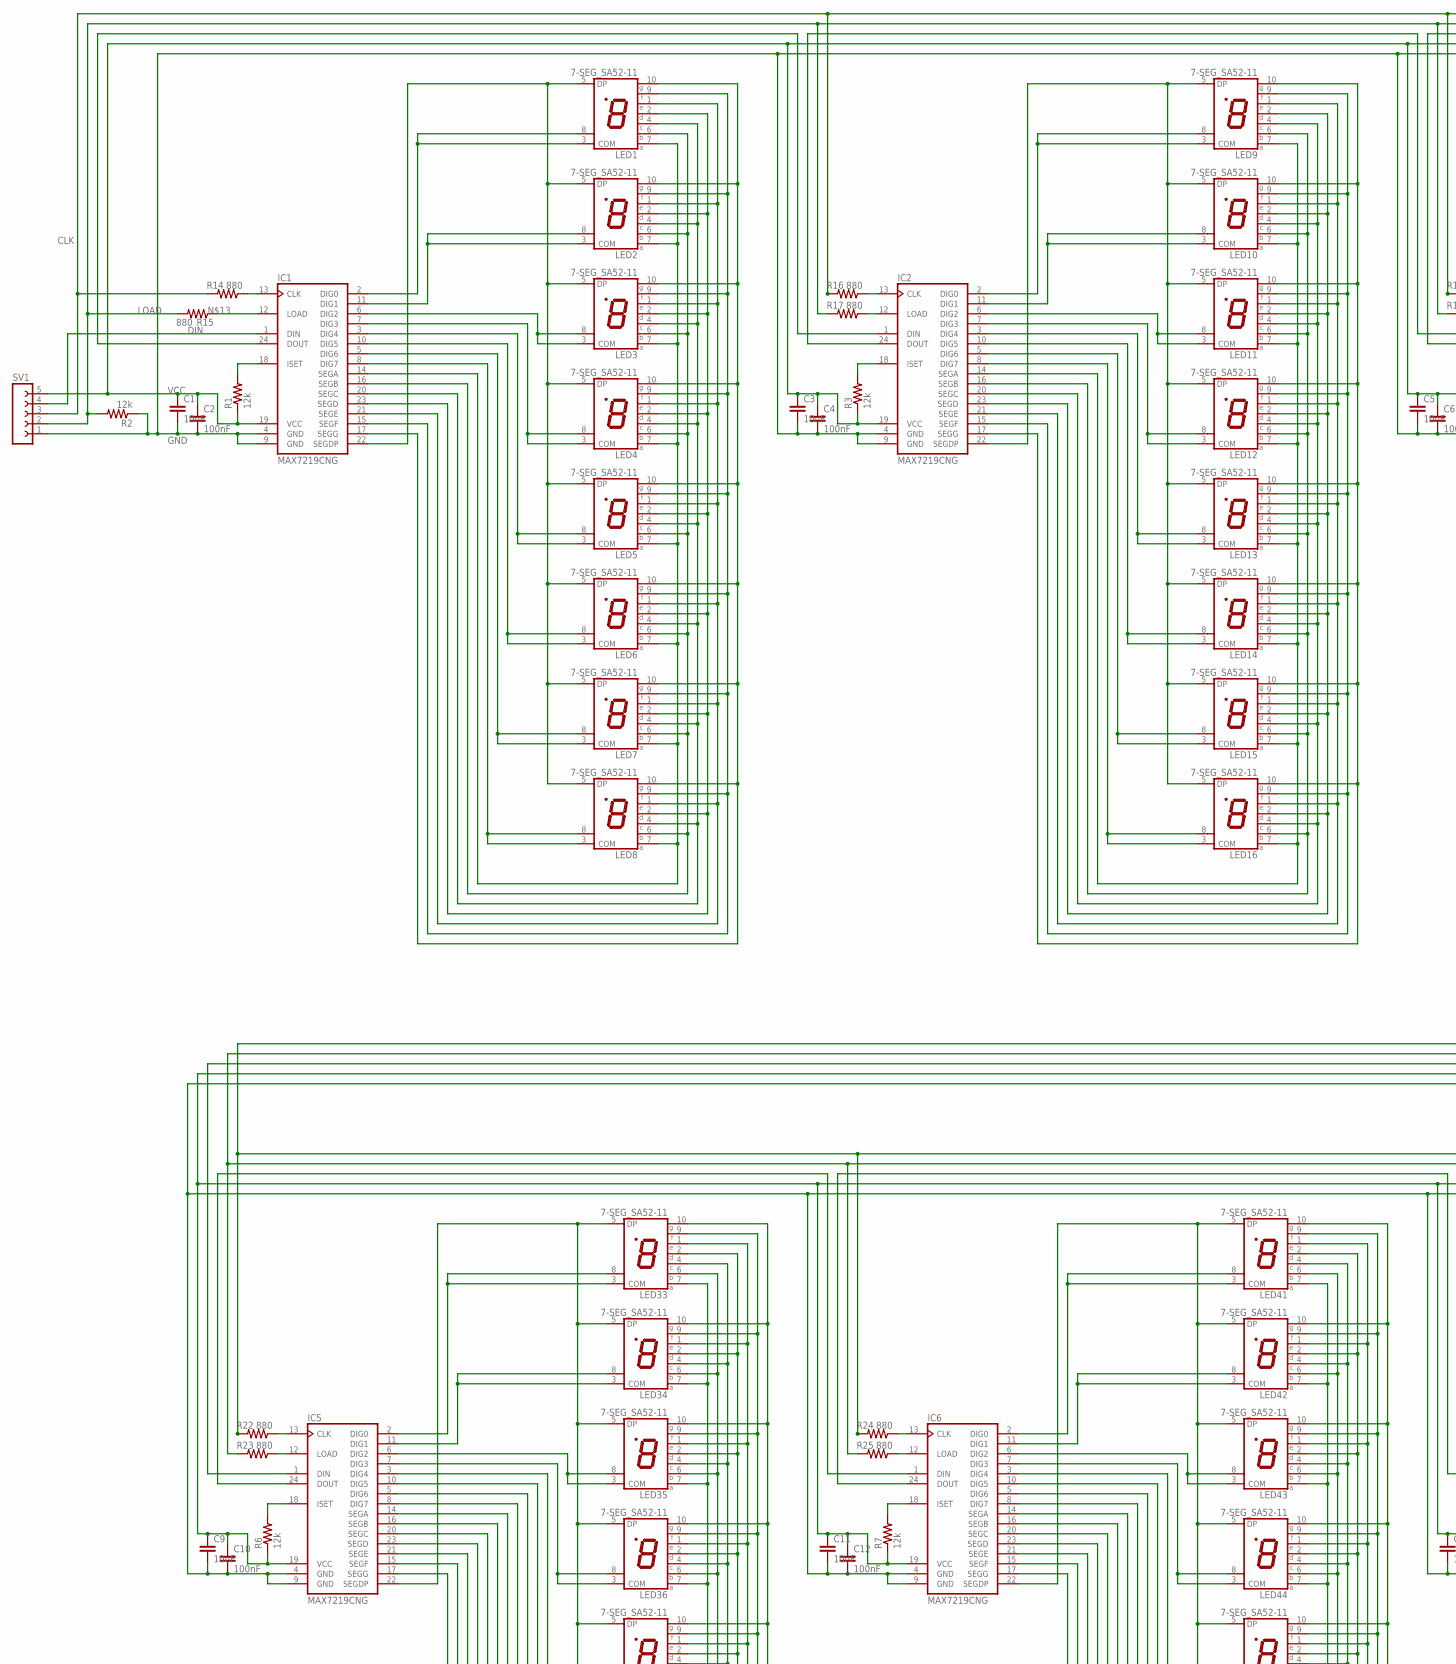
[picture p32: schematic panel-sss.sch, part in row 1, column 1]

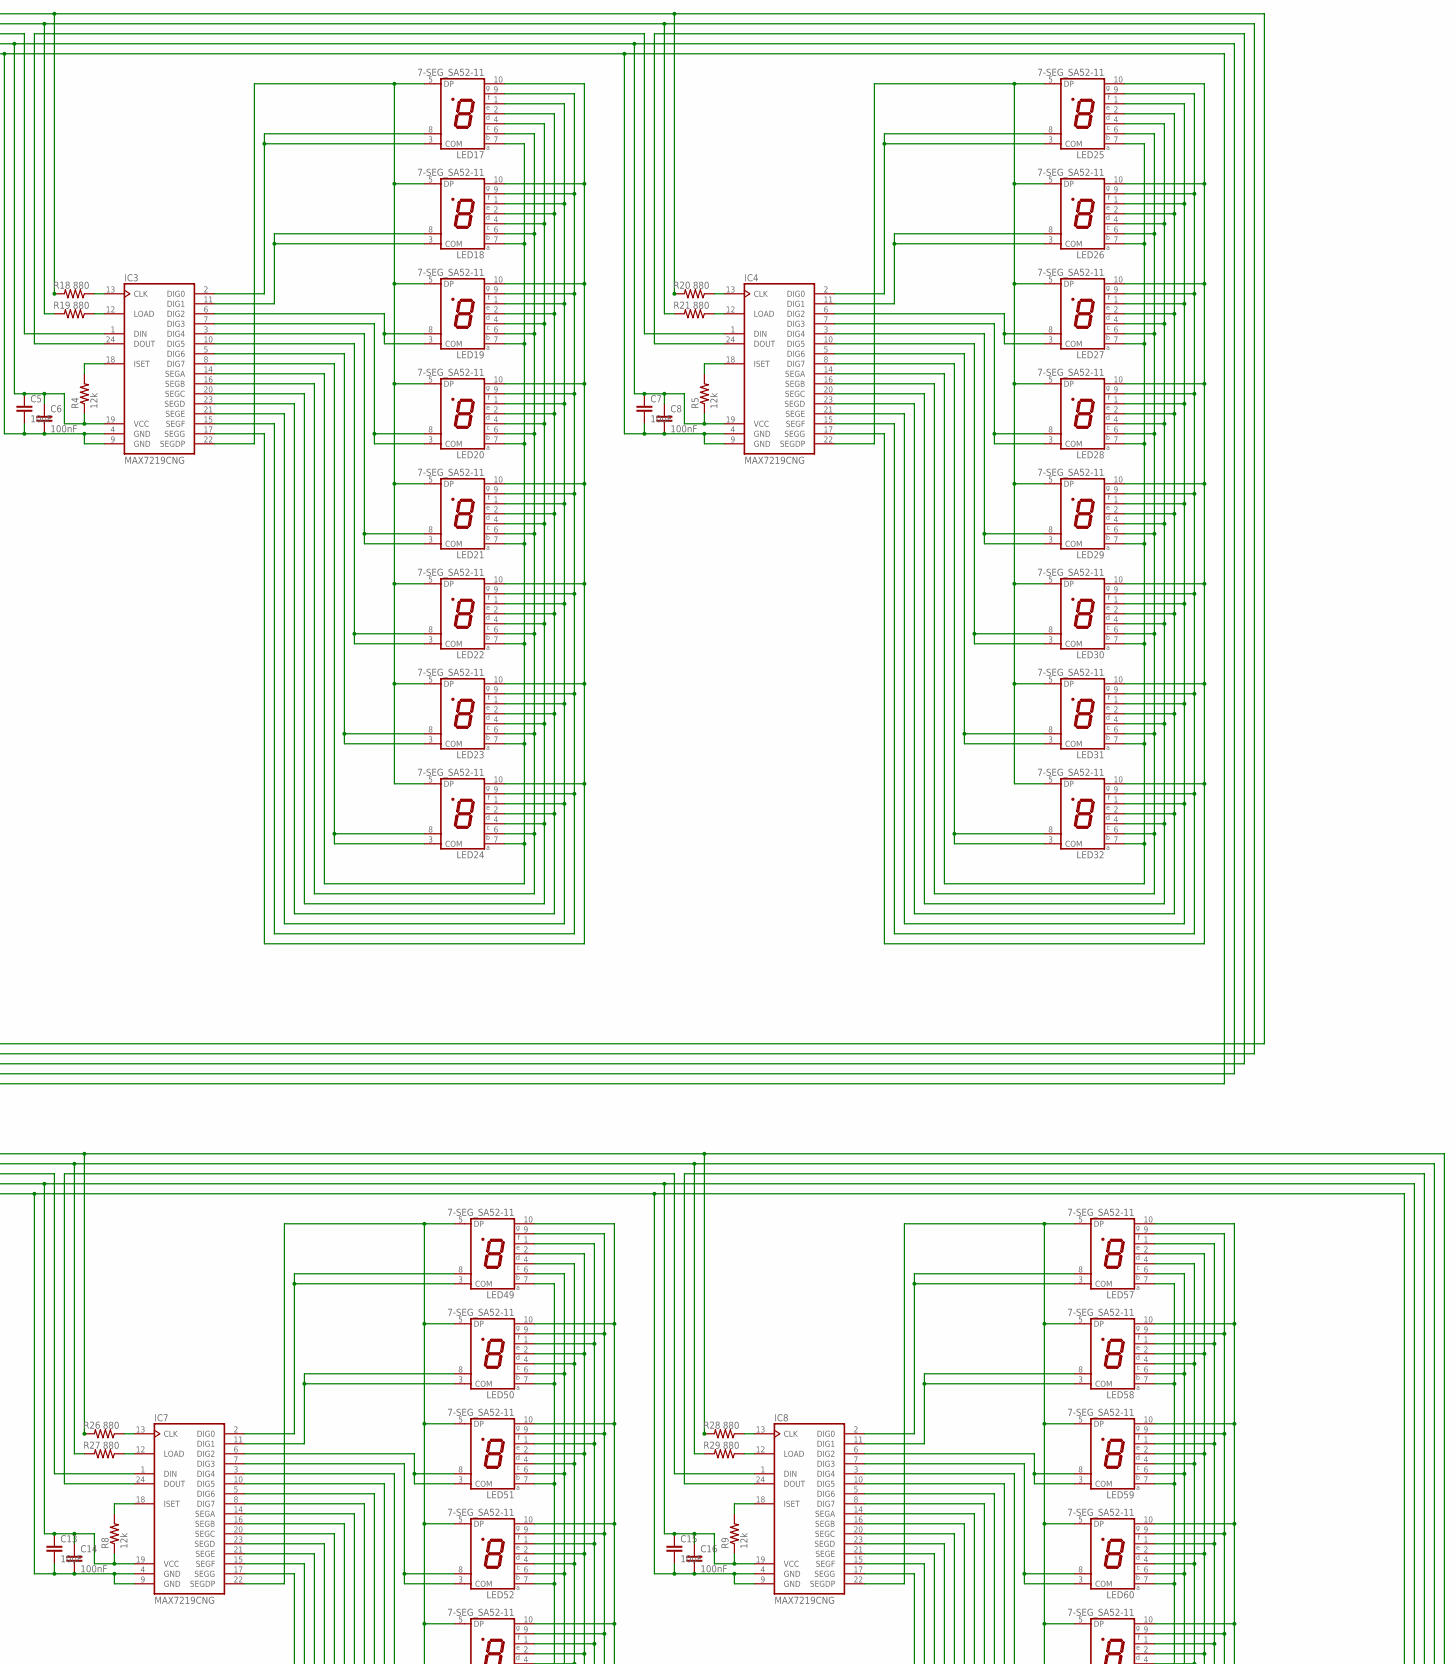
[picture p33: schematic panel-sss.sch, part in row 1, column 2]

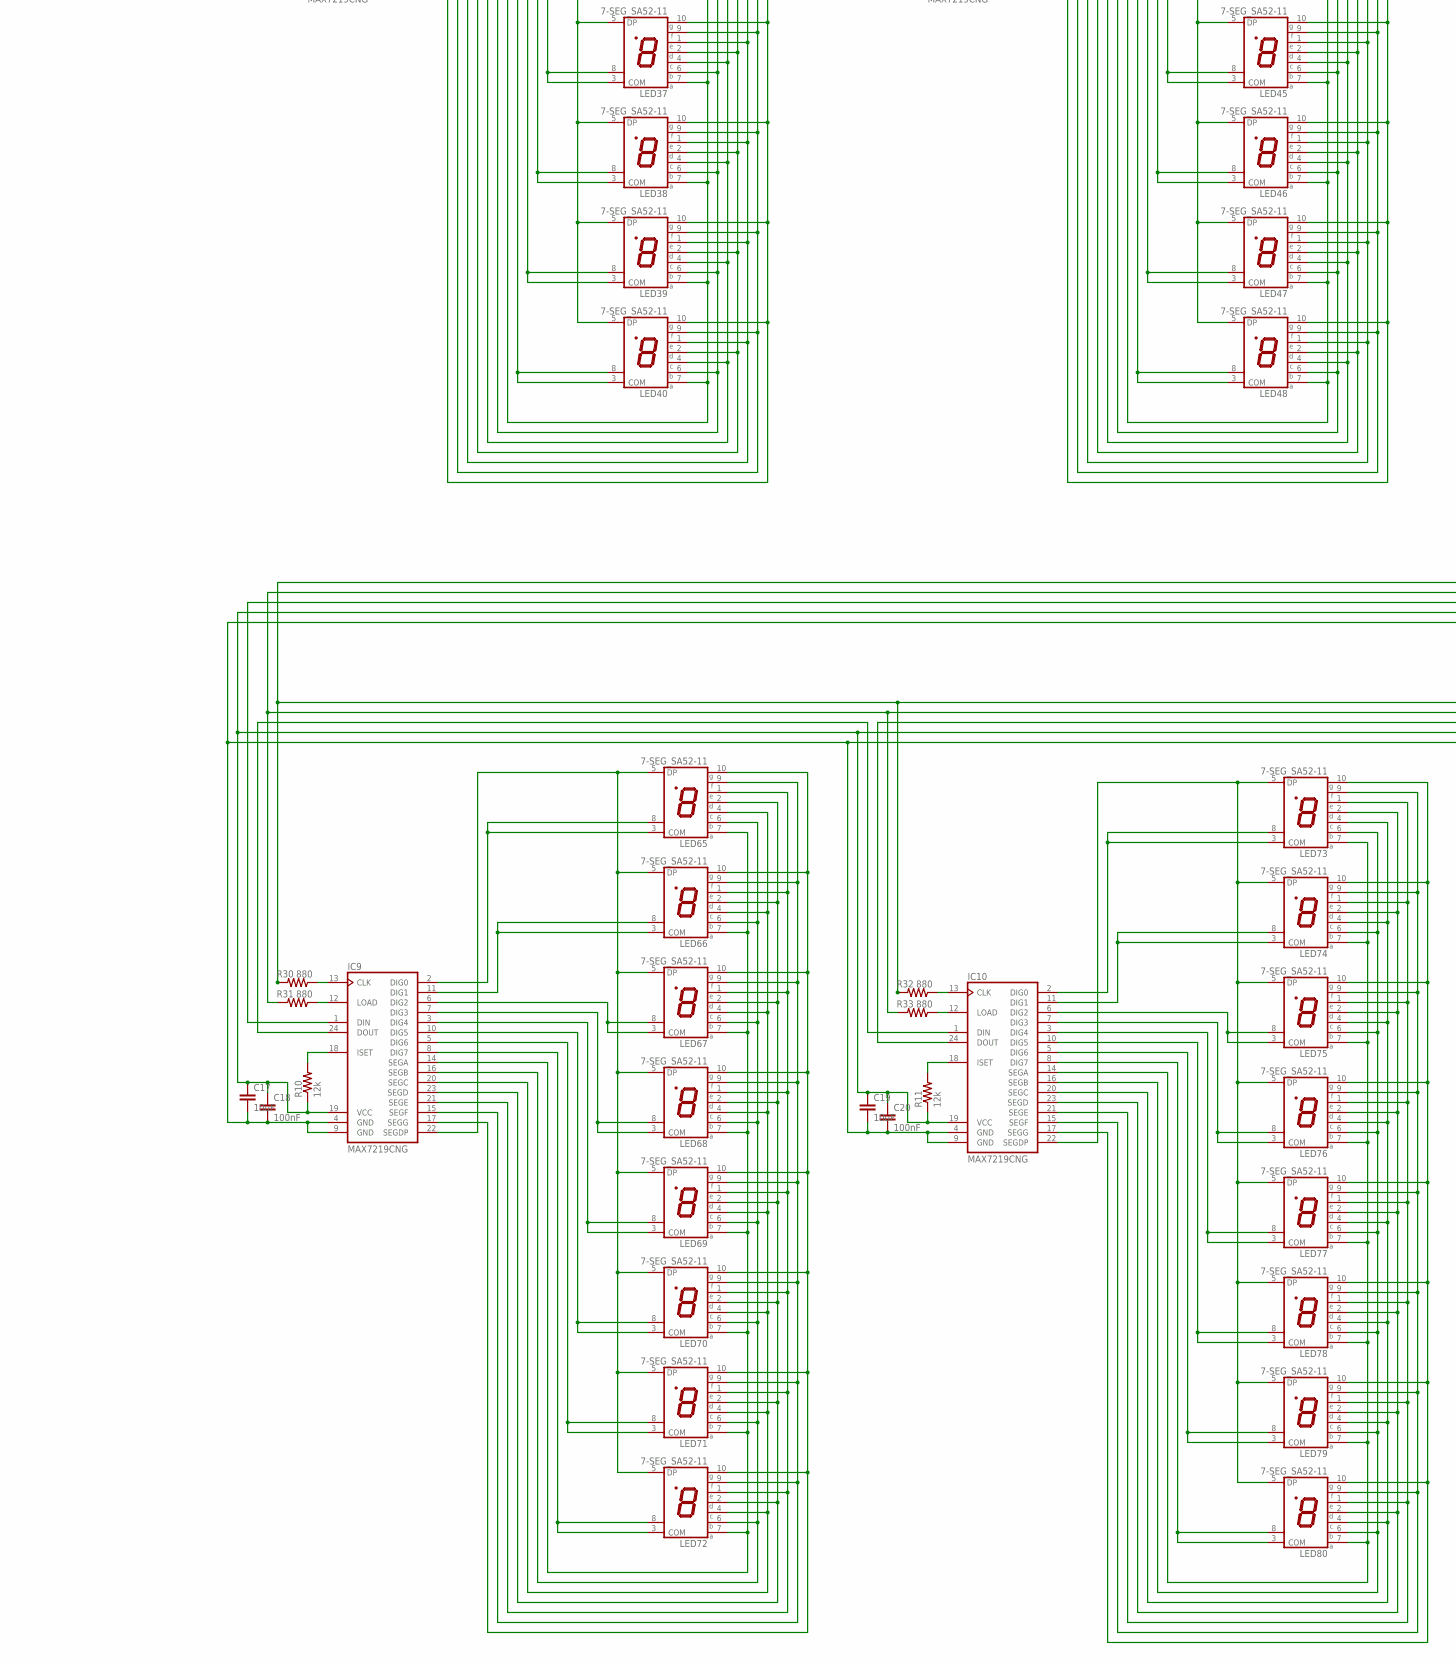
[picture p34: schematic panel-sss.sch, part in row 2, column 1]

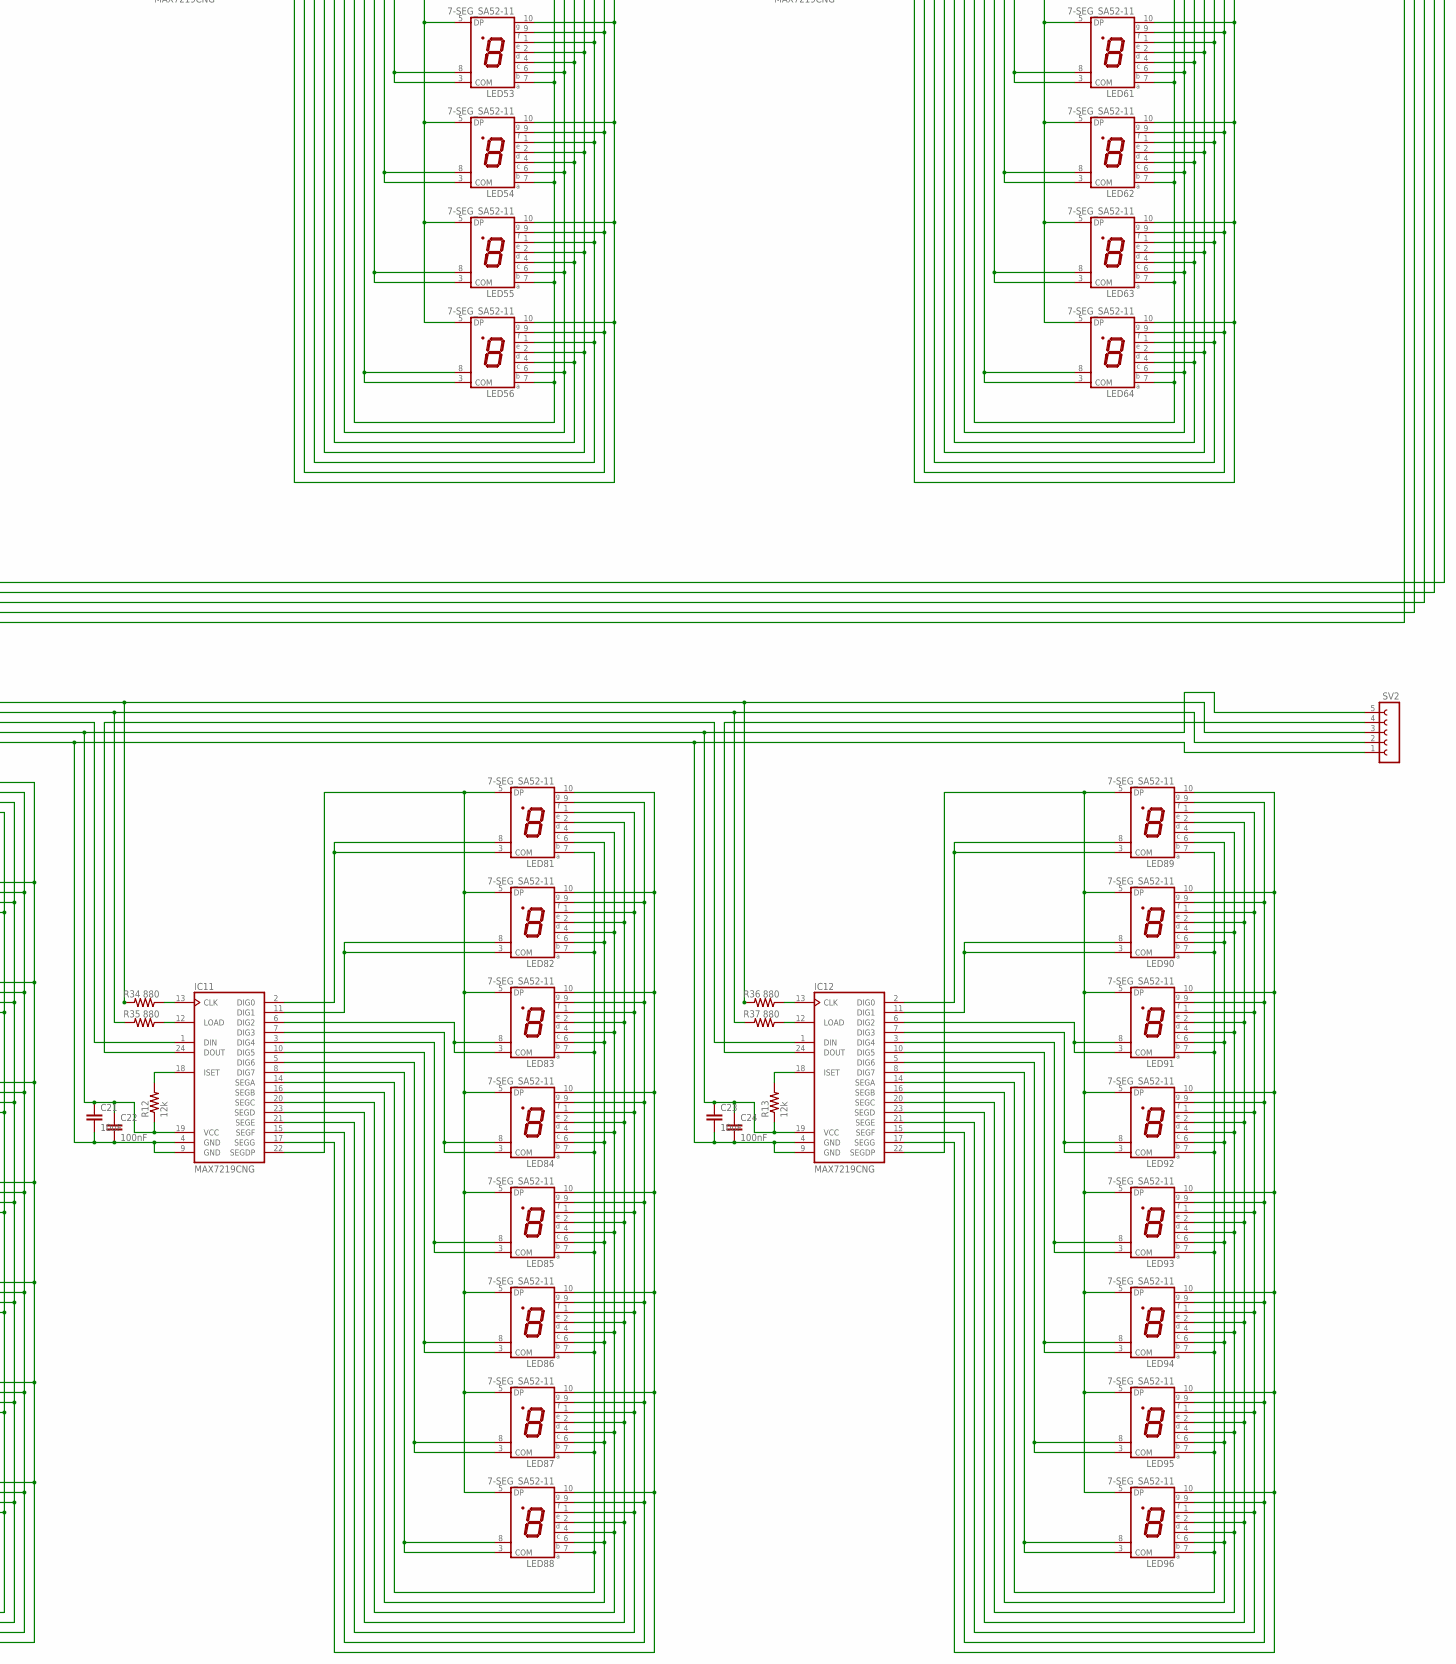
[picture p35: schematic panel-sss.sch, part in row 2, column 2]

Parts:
C1, C3, C5, C7, C9, C11, C13, C15, C17, C19, C21, C23: 10uF; C2.5-2
C2, C4, C6, C8, C10, C12, C14, C16, C18, C20, C22, C24: 100nF; C2.5-2
IC1, IC2, IC3, IC4, IC5, IC6, IC7, IC8, IC9, IC10, IC11, IC12: MAX7219CNG; DIL24-3
LED1, LED2, LED3, LED4, LED5, LED6, LED7, LED8, LED9, LED10, LED11, LED12, LED13, LED14, LED15, LED16, LED17, LED18, LED19, LED20, LED21, LED22, LED23, LED24, LED25, LED26, LED27, LED28, LED29, LED30, LED31, LED32, LED33, LED34, LED35, LED36, LED37, LED38, LED39, LED40, LED41, LED42, LED43, LED44, LED45, LED46, LED47, LED48, LED49, LED50, LED51, LED52, LED53, LED54, LED55, LED56, LED57, LED58, LED59, LED60, LED61, LED62, LED63, LED64, LED65, LED66, LED67, LED68, LED69, LED70, LED71, LED72, LED73, LED74, LED75, LED76, LED77, LED78, LED79, LED80, LED81, LED82, LED83, LED84, LED85, LED86, LED87, LED88, LED89, LED90, LED91, LED92, LED93, LED94, LED95, LED96: 7-SEG_SA52-11; SA52-11
R1, R2, R3, R4, R5, R6, R7, R8, R9, R10, R11, R12, R13: 12k; 0204/7
R14, R15, R16, R17, R18, R19, R20, R21, R22, R23, R24, R25, R26, R27, R28, R29, R30, R31, R32, R33, R34, R35, R36, R37: 880; 0204/7
SV1, SV2: FE05-1

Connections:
CLK: R14.2, R16.2, R18.2, R20.2, R22.2, R24.2, R26.2, R28.2, R30.2, R32.2, R34.2, R36.2, SV1.3, SV2.3
DIN: IC1.1 (DIN), SV1.4
GND: C1.2, C2.2, C3.2, C4.2, C5.2, C6.2, C7.2, C8.2, C9.2, C10.2, C11.2, C12.2, C13.2, C14.2, C15.2, C16.2, C17.2, C18.2, C19.2, C20.2, C21.2, C22.2, C23.2, C24.2, IC1.4 (GND), IC1.9 (GND), IC2.4 (GND), IC2.9 (GND), IC3.4 (GND), IC3.9 (GND), IC4.4 (GND), IC4.9 (GND), IC5.4 (GND), IC5.9 (GND), IC6.4 (GND), IC6.9 (GND), IC7.4 (GND), IC7.9 (GND), IC8.4 (GND), IC8.9 (GND), IC9.4 (GND), IC9.9 (GND), IC10.4 (GND), IC10.9 (GND), IC11.4 (GND), IC11.9 (GND), IC12.4 (GND), IC12.9 (GND), R2.1, SV1.1, SV2.1
LOAD: R2.2, R15.2, R17.2, R19.2, R21.2, R23.2, R25.2, R27.2, R29.2, R31.2, R33.2, R35.2, R37.2, SV1.2, SV2.2
unnamed: IC1.2 (DIG0), LED1.3 (COM), LED1.8 (COM)
unnamed: IC1.11 (DIG1), LED2.3 (COM), LED2.8 (COM)
unnamed: IC1.6 (DIG2), LED3.3 (COM), LED3.8 (COM)
unnamed: IC1.7 (DIG3), LED4.3 (COM), LED4.8 (COM)
unnamed: IC1.3 (DIG4), LED5.3 (COM), LED5.8 (COM)
unnamed: IC1.10 (DIG5), LED6.3 (COM), LED6.8 (COM)
unnamed: IC1.5 (DIG6), LED7.3 (COM), LED7.8 (COM)
unnamed: IC1.8 (DIG7), LED8.3 (COM), LED8.8 (COM)
unnamed: IC1.15 (SEGF), LED1.9 (F), LED2.9 (F), LED3.9 (F), LED4.9 (F), LED5.9 (F), LED6.9 (F), LED7.9 (F), LED8.9 (F)
unnamed: IC2.18 (ISET), R3.2
unnamed: IC2.22 (SEGDP), LED9.5 (DP), LED10.5 (DP), LED11.5 (DP), LED12.5 (DP), LED13.5 (DP), LED14.5 (DP), LED15.5 (DP), LED16.5 (DP)
unnamed: IC1.13 (CLK), R14.1
unnamed: IC1.12 (LOAD), R15.1
unnamed: IC2.13 (CLK), R16.1
unnamed: IC2.2 (DIG0), LED9.3 (COM), LED9.8 (COM)
unnamed: IC1.18 (ISET), R1.2
unnamed: IC1.14 (SEGA), LED1.7 (A), LED2.7 (A), LED3.7 (A), LED4.7 (A), LED5.7 (A), LED6.7 (A), LED7.7 (A), LED8.7 (A)
unnamed: IC1.22 (SEGDP), LED1.5 (DP), LED2.5 (DP), LED3.5 (DP), LED4.5 (DP), LED5.5 (DP), LED6.5 (DP), LED7.5 (DP), LED8.5 (DP)
unnamed: IC1.16 (SEGB), LED1.6 (B), LED2.6 (B), LED3.6 (B), LED4.6 (B), LED5.6 (B), LED6.6 (B), LED7.6 (B), LED8.6 (B)
unnamed: IC1.20 (SEGC), LED1.4 (C), LED2.4 (C), LED3.4 (C), LED4.4 (C), LED5.4 (C), LED6.4 (C), LED7.4 (C), LED8.4 (C)
unnamed: IC1.23 (SEGD), LED1.2 (D), LED2.2 (D), LED3.2 (D), LED4.2 (D), LED5.2 (D), LED6.2 (D), LED7.2 (D), LED8.2 (D)
unnamed: IC1.21 (SEGE), LED1.1 (E), LED2.1 (E), LED3.1 (E), LED4.1 (E), LED5.1 (E), LED6.1 (E), LED7.1 (E), LED8.1 (E)
unnamed: IC2.11 (DIG1), LED10.3 (COM), LED10.8 (COM)
unnamed: IC1.17 (SEGG), LED1.10 (G), LED2.10 (G), LED3.10 (G), LED4.10 (G), LED5.10 (G), LED6.10 (G), LED7.10 (G), LED8.10 (G)
unnamed: IC2.6 (DIG2), LED11.3 (COM), LED11.8 (COM)
unnamed: IC2.7 (DIG3), LED12.3 (COM), LED12.8 (COM)
unnamed: IC2.3 (DIG4), LED13.3 (COM), LED13.8 (COM)
unnamed: IC2.10 (DIG5), LED14.3 (COM), LED14.8 (COM)
unnamed: IC2.5 (DIG6), LED15.3 (COM), LED15.8 (COM)
unnamed: IC2.8 (DIG7), LED16.3 (COM), LED16.8 (COM)
unnamed: IC2.14 (SEGA), LED9.7 (A), LED10.7 (A), LED11.7 (A), LED12.7 (A), LED13.7 (A), LED14.7 (A), LED15.7 (A), LED16.7 (A)
unnamed: IC2.16 (SEGB), LED9.6 (B), LED10.6 (B), LED11.6 (B), LED12.6 (B), LED13.6 (B), LED14.6 (B), LED15.6 (B), LED16.6 (B)
unnamed: IC2.20 (SEGC), LED9.4 (C), LED10.4 (C), LED11.4 (C), LED12.4 (C), LED13.4 (C), LED14.4 (C), LED15.4 (C), LED16.4 (C)
unnamed: IC2.23 (SEGD), LED9.2 (D), LED10.2 (D), LED11.2 (D), LED12.2 (D), LED13.2 (D), LED14.2 (D), LED15.2 (D), LED16.2 (D)
unnamed: IC2.21 (SEGE), LED9.1 (E), LED10.1 (E), LED11.1 (E), LED12.1 (E), LED13.1 (E), LED14.1 (E), LED15.1 (E), LED16.1 (E)
unnamed: IC2.17 (SEGG), LED9.10 (G), LED10.10 (G), LED11.10 (G), LED12.10 (G), LED13.10 (G), LED14.10 (G), LED15.10 (G), LED16.10 (G)
unnamed: IC2.15 (SEGF), LED9.9 (F), LED10.9 (F), LED11.9 (F), LED12.9 (F), LED13.9 (F), LED14.9 (F), LED15.9 (F), LED16.9 (F)
unnamed: IC2.24 (DOUT), IC3.1 (DIN)
unnamed: IC10.3 (DIG4), LED77.3 (COM), LED77.8 (COM)
unnamed: IC2.12 (LOAD), R17.1
unnamed: IC3.13 (CLK), R18.1
unnamed: IC1.24 (DOUT), IC2.1 (DIN)
unnamed: IC3.12 (LOAD), R19.1
unnamed: IC4.13 (CLK), R20.1
unnamed: IC4.12 (LOAD), R21.1
unnamed: IC3.18 (ISET), R4.2
unnamed: IC3.22 (SEGDP), LED17.5 (DP), LED18.5 (DP), LED19.5 (DP), LED20.5 (DP), LED21.5 (DP), LED22.5 (DP), LED23.5 (DP), LED24.5 (DP)
unnamed: IC3.2 (DIG0), LED17.3 (COM), LED17.8 (COM)
unnamed: IC3.11 (DIG1), LED18.3 (COM), LED18.8 (COM)
unnamed: IC3.6 (DIG2), LED19.3 (COM), LED19.8 (COM)
unnamed: IC3.7 (DIG3), LED20.3 (COM), LED20.8 (COM)
unnamed: IC3.3 (DIG4), LED21.3 (COM), LED21.8 (COM)
unnamed: IC3.10 (DIG5), LED22.3 (COM), LED22.8 (COM)
unnamed: IC3.5 (DIG6), LED23.3 (COM), LED23.8 (COM)
unnamed: IC3.8 (DIG7), LED24.3 (COM), LED24.8 (COM)
unnamed: IC3.14 (SEGA), LED17.7 (A), LED18.7 (A), LED19.7 (A), LED20.7 (A), LED21.7 (A), LED22.7 (A), LED23.7 (A), LED24.7 (A)
unnamed: IC3.16 (SEGB), LED17.6 (B), LED18.6 (B), LED19.6 (B), LED20.6 (B), LED21.6 (B), LED22.6 (B), LED23.6 (B), LED24.6 (B)
unnamed: IC3.20 (SEGC), LED17.4 (C), LED18.4 (C), LED19.4 (C), LED20.4 (C), LED21.4 (C), LED22.4 (C), LED23.4 (C), LED24.4 (C)
unnamed: IC3.23 (SEGD), LED17.2 (D), LED18.2 (D), LED19.2 (D), LED20.2 (D), LED21.2 (D), LED22.2 (D), LED23.2 (D), LED24.2 (D)
unnamed: IC3.21 (SEGE), LED17.1 (E), LED18.1 (E), LED19.1 (E), LED20.1 (E), LED21.1 (E), LED22.1 (E), LED23.1 (E), LED24.1 (E)
unnamed: IC3.17 (SEGG), LED17.10 (G), LED18.10 (G), LED19.10 (G), LED20.10 (G), LED21.10 (G), LED22.10 (G), LED23.10 (G), LED24.10 (G)
unnamed: IC3.15 (SEGF), LED17.9 (F), LED18.9 (F), LED19.9 (F), LED20.9 (F), LED21.9 (F), LED22.9 (F), LED23.9 (F), LED24.9 (F)
unnamed: IC5.13 (CLK), R22.1
unnamed: IC5.12 (LOAD), R23.1
unnamed: IC6.13 (CLK), R24.1
unnamed: IC4.18 (ISET), R5.2
unnamed: IC3.24 (DOUT), IC4.1 (DIN)
unnamed: IC4.22 (SEGDP), LED25.5 (DP), LED26.5 (DP), LED27.5 (DP), LED28.5 (DP), LED29.5 (DP), LED30.5 (DP), LED31.5 (DP), LED32.5 (DP)
unnamed: IC4.2 (DIG0), LED25.3 (COM), LED25.8 (COM)
unnamed: IC4.11 (DIG1), LED26.3 (COM), LED26.8 (COM)
unnamed: IC4.6 (DIG2), LED27.3 (COM), LED27.8 (COM)
unnamed: IC4.7 (DIG3), LED28.3 (COM), LED28.8 (COM)
unnamed: IC4.3 (DIG4), LED29.3 (COM), LED29.8 (COM)
unnamed: IC4.10 (DIG5), LED30.3 (COM), LED30.8 (COM)
unnamed: IC4.5 (DIG6), LED31.3 (COM), LED31.8 (COM)
unnamed: IC4.8 (DIG7), LED32.3 (COM), LED32.8 (COM)
unnamed: IC4.14 (SEGA), LED25.7 (A), LED26.7 (A), LED27.7 (A), LED28.7 (A), LED29.7 (A), LED30.7 (A), LED31.7 (A), LED32.7 (A)
unnamed: IC4.16 (SEGB), LED25.6 (B), LED26.6 (B), LED27.6 (B), LED28.6 (B), LED29.6 (B), LED30.6 (B), LED31.6 (B), LED32.6 (B)
unnamed: IC4.20 (SEGC), LED25.4 (C), LED26.4 (C), LED27.4 (C), LED28.4 (C), LED29.4 (C), LED30.4 (C), LED31.4 (C), LED32.4 (C)
unnamed: IC4.23 (SEGD), LED25.2 (D), LED26.2 (D), LED27.2 (D), LED28.2 (D), LED29.2 (D), LED30.2 (D), LED31.2 (D), LED32.2 (D)
unnamed: IC4.21 (SEGE), LED25.1 (E), LED26.1 (E), LED27.1 (E), LED28.1 (E), LED29.1 (E), LED30.1 (E), LED31.1 (E), LED32.1 (E)
unnamed: IC4.17 (SEGG), LED25.10 (G), LED26.10 (G), LED27.10 (G), LED28.10 (G), LED29.10 (G), LED30.10 (G), LED31.10 (G), LED32.10 (G)
unnamed: IC4.15 (SEGF), LED25.9 (F), LED26.9 (F), LED27.9 (F), LED28.9 (F), LED29.9 (F), LED30.9 (F), LED31.9 (F), LED32.9 (F)
unnamed: IC6.12 (LOAD), R25.1
unnamed: IC4.24 (DOUT), IC5.1 (DIN)
unnamed: IC7.13 (CLK), R26.1
unnamed: IC7.12 (LOAD), R27.1
unnamed: IC8.13 (CLK), R28.1
unnamed: IC8.12 (LOAD), R29.1
unnamed: IC9.13 (CLK), R30.1
unnamed: IC5.18 (ISET), R6.2
unnamed: IC5.22 (SEGDP), LED33.5 (DP), LED34.5 (DP), LED35.5 (DP), LED36.5 (DP), LED37.5 (DP), LED38.5 (DP), LED39.5 (DP), LED40.5 (DP)
unnamed: IC5.2 (DIG0), LED33.3 (COM), LED33.8 (COM)
unnamed: IC5.11 (DIG1), LED34.3 (COM), LED34.8 (COM)
unnamed: IC5.6 (DIG2), LED35.3 (COM), LED35.8 (COM)
unnamed: IC5.7 (DIG3), LED36.3 (COM), LED36.8 (COM)
unnamed: IC5.3 (DIG4), LED37.3 (COM), LED37.8 (COM)
unnamed: IC5.10 (DIG5), LED38.3 (COM), LED38.8 (COM)
unnamed: IC5.5 (DIG6), LED39.3 (COM), LED39.8 (COM)
unnamed: IC5.8 (DIG7), LED40.3 (COM), LED40.8 (COM)
unnamed: IC5.14 (SEGA), LED33.7 (A), LED34.7 (A), LED35.7 (A), LED36.7 (A), LED37.7 (A), LED38.7 (A), LED39.7 (A), LED40.7 (A)
unnamed: IC5.16 (SEGB), LED33.6 (B), LED34.6 (B), LED35.6 (B), LED36.6 (B), LED37.6 (B), LED38.6 (B), LED39.6 (B), LED40.6 (B)
unnamed: IC5.20 (SEGC), LED33.4 (C), LED34.4 (C), LED35.4 (C), LED36.4 (C), LED37.4 (C), LED38.4 (C), LED39.4 (C), LED40.4 (C)
unnamed: IC5.23 (SEGD), LED33.2 (D), LED34.2 (D), LED35.2 (D), LED36.2 (D), LED37.2 (D), LED38.2 (D), LED39.2 (D), LED40.2 (D)
unnamed: IC5.21 (SEGE), LED33.1 (E), LED34.1 (E), LED35.1 (E), LED36.1 (E), LED37.1 (E), LED38.1 (E), LED39.1 (E), LED40.1 (E)
unnamed: IC5.17 (SEGG), LED33.10 (G), LED34.10 (G), LED35.10 (G), LED36.10 (G), LED37.10 (G), LED38.10 (G), LED39.10 (G), LED40.10 (G)
unnamed: IC5.15 (SEGF), LED33.9 (F), LED34.9 (F), LED35.9 (F), LED36.9 (F), LED37.9 (F), LED38.9 (F), LED39.9 (F), LED40.9 (F)
unnamed: IC9.12 (LOAD), R31.1
unnamed: IC5.24 (DOUT), IC6.1 (DIN)
unnamed: IC10.13 (CLK), R32.1
unnamed: IC10.12 (LOAD), R33.1
unnamed: IC11.13 (CLK), R34.1
unnamed: IC11.12 (LOAD), R35.1
unnamed: IC12.13 (CLK), R36.1
unnamed: IC6.18 (ISET), R7.2
unnamed: IC6.22 (SEGDP), LED41.5 (DP), LED42.5 (DP), LED43.5 (DP), LED44.5 (DP), LED45.5 (DP), LED46.5 (DP), LED47.5 (DP), LED48.5 (DP)
unnamed: IC6.2 (DIG0), LED41.3 (COM), LED41.8 (COM)
unnamed: IC6.11 (DIG1), LED42.3 (COM), LED42.8 (COM)
unnamed: IC6.6 (DIG2), LED43.3 (COM), LED43.8 (COM)
unnamed: IC6.7 (DIG3), LED44.3 (COM), LED44.8 (COM)
unnamed: IC6.3 (DIG4), LED45.3 (COM), LED45.8 (COM)
unnamed: IC6.10 (DIG5), LED46.3 (COM), LED46.8 (COM)
unnamed: IC6.5 (DIG6), LED47.3 (COM), LED47.8 (COM)
unnamed: IC6.8 (DIG7), LED48.3 (COM), LED48.8 (COM)
unnamed: IC6.14 (SEGA), LED41.7 (A), LED42.7 (A), LED43.7 (A), LED44.7 (A), LED45.7 (A), LED46.7 (A), LED47.7 (A), LED48.7 (A)
unnamed: IC6.16 (SEGB), LED41.6 (B), LED42.6 (B), LED43.6 (B), LED44.6 (B), LED45.6 (B), LED46.6 (B), LED47.6 (B), LED48.6 (B)
unnamed: IC6.20 (SEGC), LED41.4 (C), LED42.4 (C), LED43.4 (C), LED44.4 (C), LED45.4 (C), LED46.4 (C), LED47.4 (C), LED48.4 (C)
unnamed: IC6.23 (SEGD), LED41.2 (D), LED42.2 (D), LED43.2 (D), LED44.2 (D), LED45.2 (D), LED46.2 (D), LED47.2 (D), LED48.2 (D)
unnamed: IC6.21 (SEGE), LED41.1 (E), LED42.1 (E), LED43.1 (E), LED44.1 (E), LED45.1 (E), LED46.1 (E), LED47.1 (E), LED48.1 (E)
unnamed: IC6.17 (SEGG), LED41.10 (G), LED42.10 (G), LED43.10 (G), LED44.10 (G), LED45.10 (G), LED46.10 (G), LED47.10 (G), LED48.10 (G)
unnamed: IC6.15 (SEGF), LED41.9 (F), LED42.9 (F), LED43.9 (F), LED44.9 (F), LED45.9 (F), LED46.9 (F), LED47.9 (F), LED48.9 (F)
unnamed: IC12.12 (LOAD), R37.1
unnamed: IC6.24 (DOUT), IC7.1 (DIN)
unnamed: IC7.18 (ISET), R8.2
unnamed: IC7.22 (SEGDP), LED49.5 (DP), LED50.5 (DP), LED51.5 (DP), LED52.5 (DP), LED53.5 (DP), LED54.5 (DP), LED55.5 (DP), LED56.5 (DP)
unnamed: IC7.2 (DIG0), LED49.3 (COM), LED49.8 (COM)
unnamed: IC7.11 (DIG1), LED50.3 (COM), LED50.8 (COM)
unnamed: IC7.6 (DIG2), LED51.3 (COM), LED51.8 (COM)
unnamed: IC7.7 (DIG3), LED52.3 (COM), LED52.8 (COM)
unnamed: IC7.3 (DIG4), LED53.3 (COM), LED53.8 (COM)
unnamed: IC7.10 (DIG5), LED54.3 (COM), LED54.8 (COM)
unnamed: IC7.5 (DIG6), LED55.3 (COM), LED55.8 (COM)
unnamed: IC7.8 (DIG7), LED56.3 (COM), LED56.8 (COM)
unnamed: IC7.14 (SEGA), LED49.7 (A), LED50.7 (A), LED51.7 (A), LED52.7 (A), LED53.7 (A), LED54.7 (A), LED55.7 (A), LED56.7 (A)
unnamed: IC7.16 (SEGB), LED49.6 (B), LED50.6 (B), LED51.6 (B), LED52.6 (B), LED53.6 (B), LED54.6 (B), LED55.6 (B), LED56.6 (B)
unnamed: IC7.20 (SEGC), LED49.4 (C), LED50.4 (C), LED51.4 (C), LED52.4 (C), LED53.4 (C), LED54.4 (C), LED55.4 (C), LED56.4 (C)
unnamed: IC7.23 (SEGD), LED49.2 (D), LED50.2 (D), LED51.2 (D), LED52.2 (D), LED53.2 (D), LED54.2 (D), LED55.2 (D), LED56.2 (D)
unnamed: IC7.21 (SEGE), LED49.1 (E), LED50.1 (E), LED51.1 (E), LED52.1 (E), LED53.1 (E), LED54.1 (E), LED55.1 (E), LED56.1 (E)
unnamed: IC7.17 (SEGG), LED49.10 (G), LED50.10 (G), LED51.10 (G), LED52.10 (G), LED53.10 (G), LED54.10 (G), LED55.10 (G), LED56.10 (G)
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

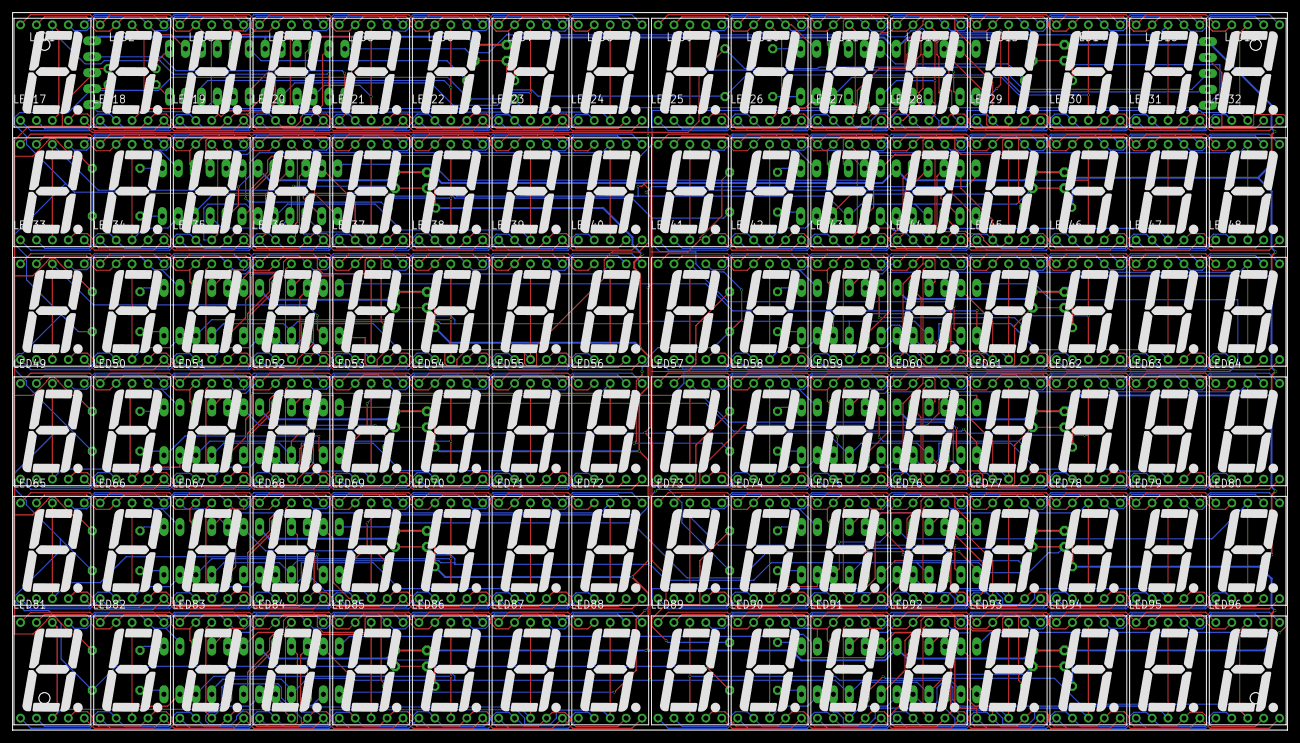
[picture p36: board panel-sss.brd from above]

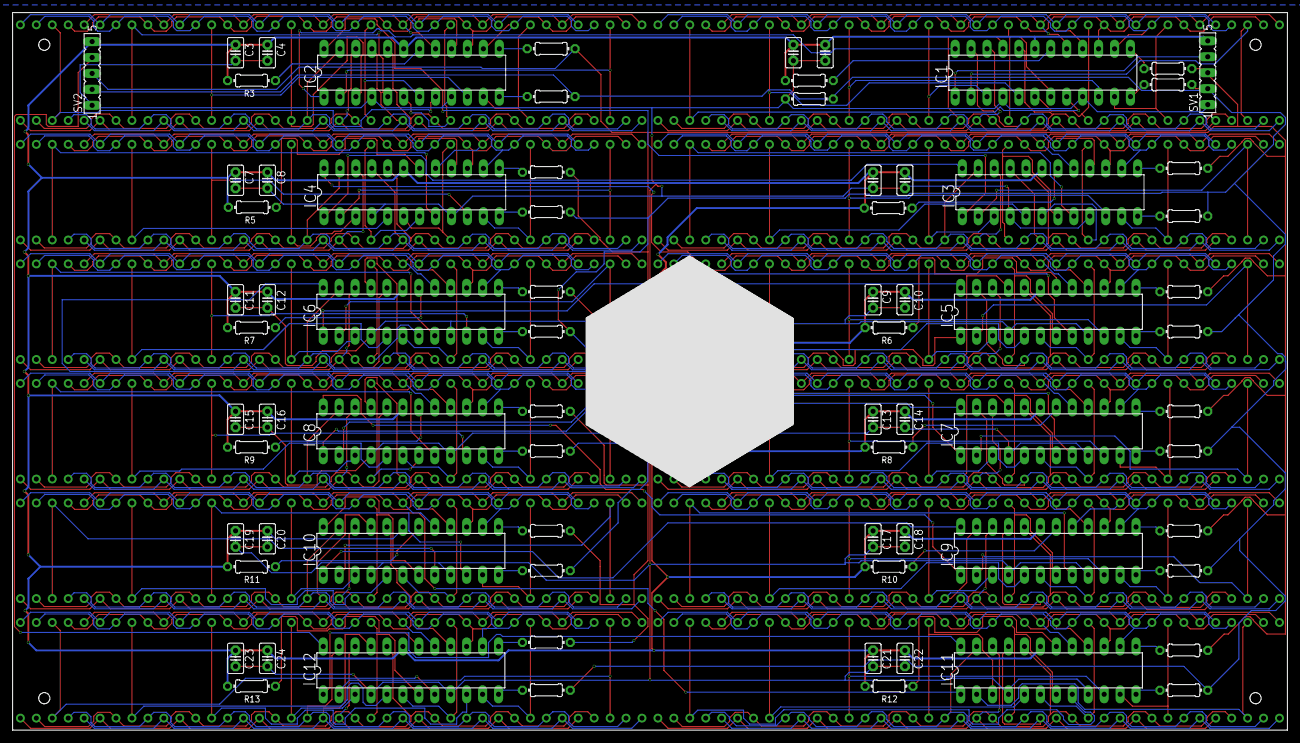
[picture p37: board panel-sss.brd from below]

Board: 2 copper layers, 203.2 x 114.4 mm, 171 parts (75 on the bottom side), 245 nets.

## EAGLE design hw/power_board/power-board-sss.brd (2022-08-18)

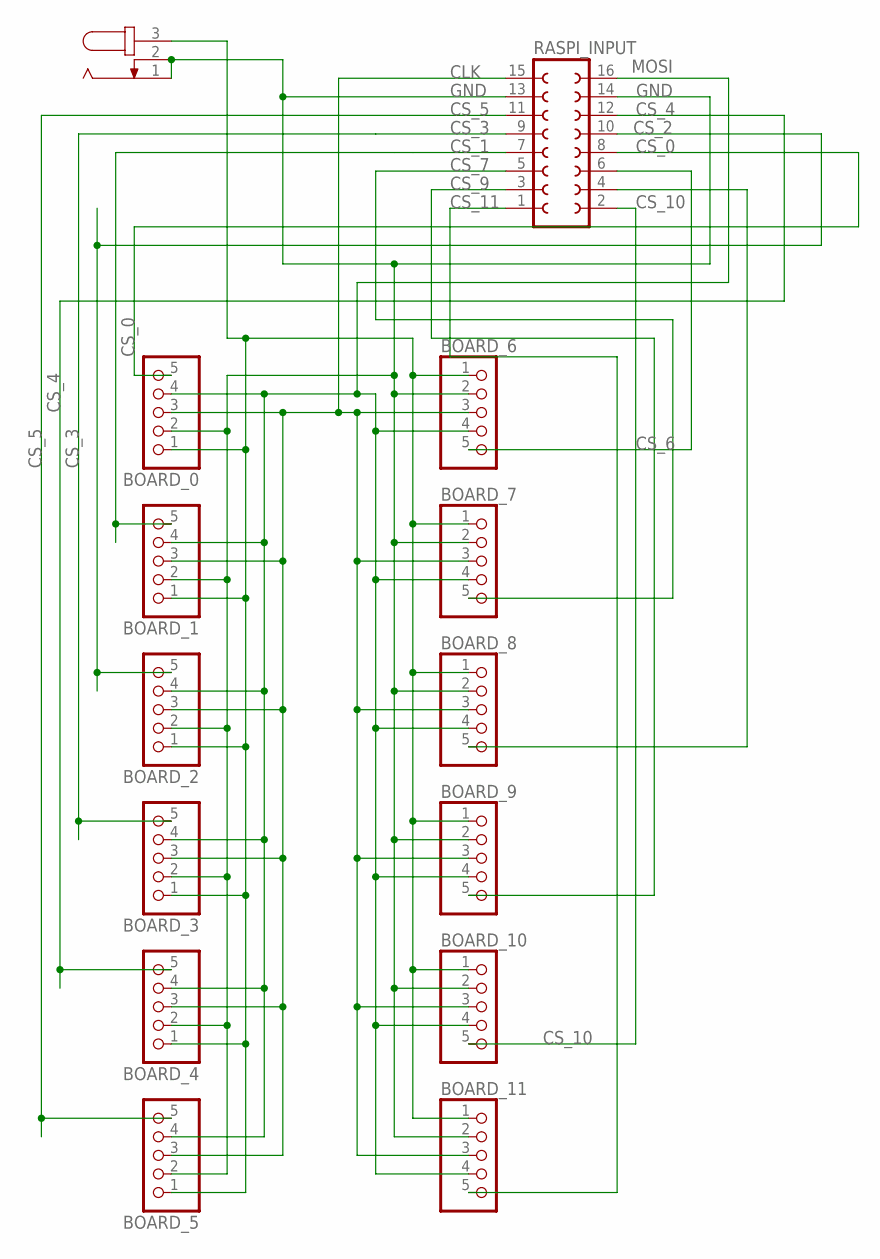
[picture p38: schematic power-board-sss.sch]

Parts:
BOARD_0, BOARD_1, BOARD_2, BOARD_3, BOARD_4, BOARD_5, BOARD_6, BOARD_7, BOARD_8, BOARD_9, BOARD_10, BOARD_11: PINHD-1X5; 1X05
J1: JACK-PLUG1; SPC4078
RASPI_INPUT: FE08-2

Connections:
CLK: BOARD_0.3, BOARD_1.3, BOARD_2.3, BOARD_3.3, BOARD_4.3, BOARD_5.3, BOARD_6.3, BOARD_7.3, BOARD_8.3, BOARD_9.3, BOARD_10.3, BOARD_11.3, RASPI_INPUT.15
CS_0: BOARD_0.5, RASPI_INPUT.8
CS_1: BOARD_1.5, RASPI_INPUT.7
CS_2: BOARD_2.5, RASPI_INPUT.10
CS_3: BOARD_3.5, RASPI_INPUT.9
CS_4: BOARD_4.5, RASPI_INPUT.12
CS_5: BOARD_5.5, RASPI_INPUT.11
CS_6: BOARD_6.5, RASPI_INPUT.6
CS_7: BOARD_7.5, RASPI_INPUT.5
CS_8: BOARD_8.5, RASPI_INPUT.4
CS_9: BOARD_9.5, RASPI_INPUT.3
CS_10: BOARD_10.5, RASPI_INPUT.2
CS_11: BOARD_11.5, RASPI_INPUT.1
GND: BOARD_0.2, BOARD_1.2, BOARD_2.2, BOARD_3.2, BOARD_4.2, BOARD_5.2, BOARD_6.2, BOARD_7.2, BOARD_8.2, BOARD_9.2, BOARD_10.2, BOARD_11.2, J1.1, J1.2, RASPI_INPUT.13, RASPI_INPUT.14
MOSI: BOARD_0.4, BOARD_1.4, BOARD_2.4, BOARD_3.4, BOARD_4.4, BOARD_5.4, BOARD_6.4, BOARD_7.4, BOARD_8.4, BOARD_9.4, BOARD_10.4, BOARD_11.4, RASPI_INPUT.16
VCC: BOARD_0.1, BOARD_1.1, BOARD_2.1, BOARD_3.1, BOARD_4.1, BOARD_5.1, BOARD_6.1, BOARD_7.1, BOARD_8.1, BOARD_9.1, BOARD_10.1, BOARD_11.1, J1.3

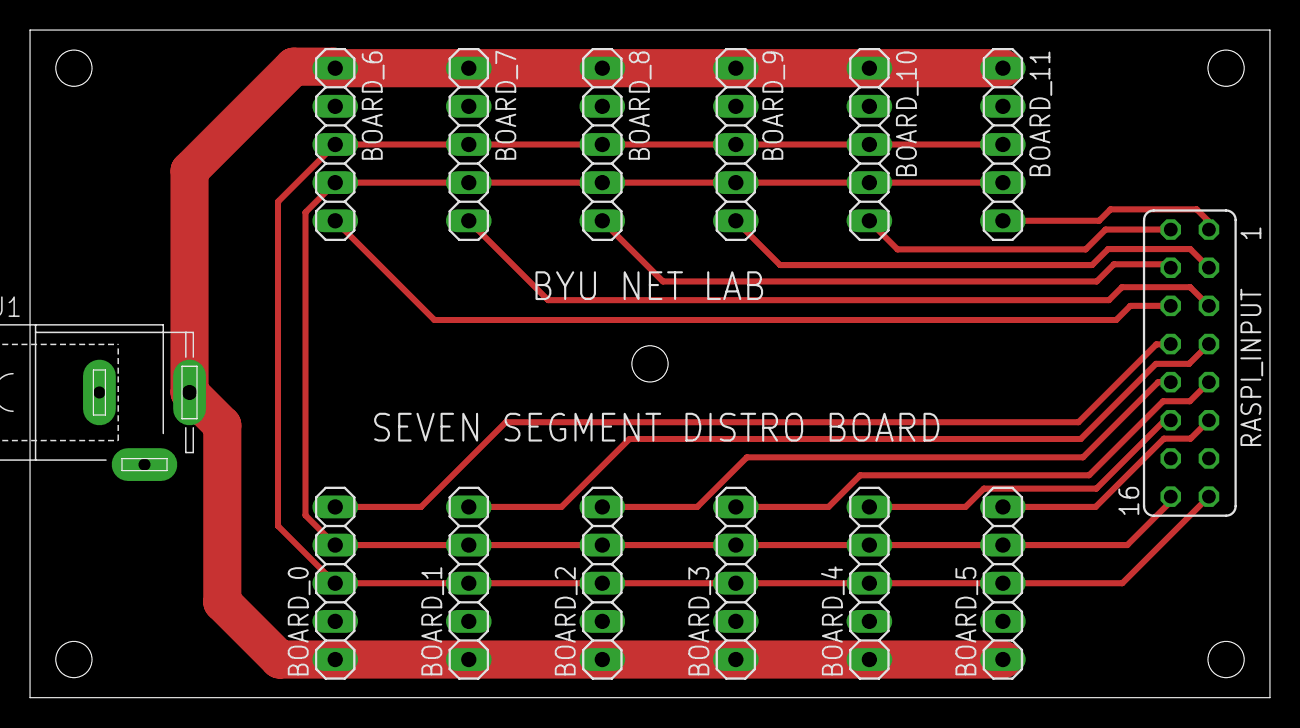
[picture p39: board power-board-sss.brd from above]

Board: 2 copper layers, 82.5 x 44.5 mm, 14 parts (0 on the bottom side), 16 nets.

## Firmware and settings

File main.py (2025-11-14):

import sys

import click
from loguru import logger

from runners import demo, kiosk, test, utils

logger_level = ["ERROR", "WARNING", "SUCCESS", "INFO", "DEBUG", "TRACE"]


@click.group()
@click.option("-v", "--verbose", count=True)
def cli(verbose):
    """CLI group."""

    if verbose >= len(logger_level):
        print(f"Only {len(logger_level) - 1} verbose flags allowed.")
        exit()

    logger.remove()  # Remove default logger

    # Start up logger
    logger.add(
        "logs/sss.log",
        rotation="00:00",
        retention="1 week",
        enqueue=True,
        backtrace=True,
        diagnose=True,
        level=logger_level[verbose],
    )

    logger.info("             ____")
    logger.info("            / . .\\")
    logger.info("            \\  ---<   Starting SSS")
    logger.info("             \\  /")
    logger.info("   __________/ /")
    logger.info("-=:___________/")


@cli.command(name="simulator")
def run_simulator():
    """CLI command to run simulator."""

    from runners import simulator  # pylint: disable=import-outside-toplevel

    simulator.run()


@cli.command(name="kiosk")
@click.option(
    "-s",
    "--simulate",
    is_flag=True,
    default=False,
    help="Run in simulated environment.",
)
@click.option(
    "-n",
    "--new_hardware",
    is_flag=True,
    default=False,
    help="Run on new hardware.",
)
@click.option(
    "testing",
    "-t",
    "--test",
    is_flag=True,
    default=False,
    help="Run in test mode. This shortens the demo time and user input time "
    "for testing purposes.",
)
def run_kiosk(simulate, new_hardware, testing):
    """CLI command to run kiosk."""
    kiosk.run(simulate, testing=testing, new_hardware=new_hardware)


@cli.command("demo")
@click.argument(
    "name",
    type=click.Choice(
        sorted([name for name, _ in utils.get_demos()]), case_sensitive=False
    ),
)
@click.option(
    "-s",
    "--simulate",
    is_flag=True,
    default=False,
    help="Run in simulated environment.",
)
@click.option(
    "-n",
    "--new_hardware",
    is_flag=True,
    default=False,
    help="Run on new hardware.",
)
@click.option(
    "testing",
    "-t",
    "--test",
    is_flag=True,
    default=False,
    help="Run in test mode. This provides feedback for if your demo is "
    "running fast enough relative to the set frame rate.",
)
def run_demo(name, simulate, new_hardware, testing):
    """CLI command to run demo."""
    demo.run(name, simulate, new_hardware, testing=testing)


@cli.command("test")
def run_test():
    """CLI command to run test."""
    test.run()


if __name__ == "__main__":
    cli()

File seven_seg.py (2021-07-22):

import spidev
from symbols import get_char2

MAX7219_DIGITS = 8

MAX7219_REG_NOOP = 0x0
MAX7219_REG_DIGIT0 = 0x1
MAX7219_REG_DIGIT1 = 0x02
MAX7219_REG_DIGIT2 = 0x3
MAX7219_REG_DIGIT3 = 0x4
MAX7219_REG_DIGIT4 = 0x5
MAX7219_REG_DIGIT5 = 0x6
MAX7219_REG_DIGIT6 = 0x7
MAX7219_REG_DIGIT7 = 0x8
MAX7219_REG_DECODEMODE = 0x9
MAX7219_REG_INTENSITY = 0xA
MAX7219_REG_SCANLIMIT = 0xB
MAX7219_REG_SHUTDOWN = 0xC
MAX7219_REG_DISPLAYTEST = 0xF

DEFAULT_BAUDRATE = 5000000


class SevenSegment:
    def __init__(
        self,
        num_digits=8,
        num_per_segment=MAX7219_DIGITS,
        baudrate=DEFAULT_BAUDRATE,
        cs_num=0,
        brightness=7,
        clear=True,
        segment_orientation_array=None,
    ):
        """Constructor

        num_digits -- total number of digits in your display (default 8)
        num_per_segment -- total number of digits per MAX7219 segment (default 8)
        baudrate -- rate at which data is transfered (default 9000kHz), excessive rate may result in instability
        cs_num -- which control select line is being used (default 0)
        brightness -- starting brightness of the leds (default 7)
        clear -- clear the screen on initialization (default True)
        segment_orientation_array -- a 2d array of where the MAX7219 segments are located, one indexed (default None)
            : example [[1, 2], [3, 4], [5, 6], [7, 8], [9, 10], [11, 12]] (height is 6 and width is 16)
            : this needs to be populated to use coordinate grid style functions i.e. letter2 (default None)
        """
        self.num_digits = num_digits
        self.num_segments = num_digits // num_per_segment
        self.num_per_segment = num_per_segment
        self.baudrate = baudrate if baudrate < 10000000 else 10000000
        self._buf = [0] * self.num_digits
        self._display_buf = [0] * self.num_digits
        self._spi = spidev.SpiDev()
        self._spi.open(0, cs_num)
        self._spi.max_speed_hz = self.baudrate

        # Setup the display
        self.command(MAX7219_REG_SHUTDOWN, 1)  # 1 enables the display
        self.command(
            MAX7219_REG_DECODEMODE, 0
        )  # 0x01, 0x0F, 0xFF for different Code B modes
        self.command(MAX7219_REG_SCANLIMIT, self.num_per_segment - 1)
        self.command(MAX7219_REG_DISPLAYTEST, 0)
        self.brightness(brightness)

        # Set up cascaded segemtn orientation stuff to enable 2 functions
        self.display = (
            None or segment_orientation_array
        )  # [[1, 2], [3, 4], [5, 6], [7, 8], [9, 10], [11, 12]]
        self._display_y_len = len(self.display) if self.display is not None else None

        self._flush_index = []
        if clear:
            self.clear()

    def command(self, register_num, value):
        """Sets control registers for each segment in the display"""
        # check register_num is good
        if register_num not in [
            MAX7219_REG_DECODEMODE,
            MAX7219_REG_INTENSITY,
            MAX7219_REG_SCANLIMIT,
            MAX7219_REG_SHUTDOWN,
            MAX7219_REG_DISPLAYTEST,
        ]:
            raise ValueError("register_num is not a correct value")
        # check value is good
        if not isinstance(value, (int)) or (value > 16 or value < 0):
            raise ValueError("value is not a correct value")
        self._write([register_num, value] * self.num_segments)

    def close(self, clear=True, shutdown=True):
        """Close the spi connection"""
        if clear:
            self.clear()
        if shutdown:
            self.command(MAX7219_REG_SHUTDOWN, 0)
        self._spi.close()

    def clear(self, flush=True):
        """Clears the buffer, and if specified, flushes the display"""
        self._buf = [0] * self.num_digits
        if flush:
            self.flush_legacy()

    def brightness(self, value):
        """Sets the brightness for all of the segments ranging from 0 - 15"""
        # check value is good
        if not isinstance(value, (int)) or (value > 16 or value < 0):
            raise ValueError("value is not a correct value")
        self.command(MAX7219_REG_INTENSITY, value)

    # Original flush, about 2 times slower than the current flush function, used in clear
    def flush_legacy(self):
        """Cascade the buffer onto the display"""
        for seg in range(self.num_segments):
            for pos in range(self.num_per_segment):
                self._write(
                    ([MAX7219_REG_NOOP, 0] * (self.num_segments - seg))
                    + [
                        pos + MAX7219_REG_DIGIT0,
                        self._buf[pos + (seg * self.num_per_segment)],
                    ]
                    + ([MAX7219_REG_NOOP, 0] * seg)
                )

    def flush(self):
        """Flush all the current changes to the display"""
        for pos in self._flush_index:
            self._write(
                [MAX7219_REG_NOOP, 0]
                * (self.num_segments - 1 - int(pos / self.num_per_segment))
                + [MAX7219_REG_DIGIT0 + pos % self.num_per_segment, self._buf[pos]]
                + [MAX7219_REG_NOOP, 0] * int(pos / self.num_per_segment)
            )
        self._flush_index.clear()

    def raw(self, position, value, flush=False):
        """Given raw 0-255 value draw symbol at given postion"""
        # Check if position is valid
        if (
            not isinstance(position, (int))
            or position < 0
            or position >= self.num_digits
        ):
            raise ValueError("position is not a valid number")
        # Check if char is int between 0 and 255
        if not isinstance(value, (int)) or value < 0 or value > 255:
            raise ValueError("value is either not an int or out of bounds (0-255)")
        self._buf[position] = value
        self._flush_index.append(position)

        if flush:
            self.flush()

    def raw2(self, x, y, value, flush=False):
        """Given raw 0-255 value draw symbol at given coordinate"""
        position = self._get_pos(x, y)
        self.raw(position, value, flush)

    def letter(self, position, char, dot=False, flush=False):
        """Outputs ascii letter as close as it can, working letters/symbols found in symbols.py"""
        # Check if position is valid
        if (
            not isinstance(position, (int))
            or position < 0
            or position >= self.num_digits
        ):
            raise ValueError("position is not a valid number")
        value = get_char2(char) | (dot << 7)
        self._buf[position] = value
        self._flush_index.append(position)
        if flush:
            self.flush()
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

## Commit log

2021-07-20 fixed a doc string
    [seven_seg.py]
2021-07-29 potential mutliple select lines boards
2021-07-29 Post multi-spi test
2021-08-03 Refactor for GUI framework :o
2021-08-12 Remove old demos files, split demos in various files, screen refactor, games refactor. Snake player is broken, snake ai needs exit
    [demos.py, display.py]
2021-08-13 fixed print statement
2021-08-24 rid the code of a print statement
2021-08-26 Fixing breakout, spin angle, speed, pause and start function, start button on controller mapped
    [display.py]
2021-10-07 Switch from threads to processes
    It seems to be working!!!
2021-10-22 Added Eagle files
    [seven_seg.brd, seven_seg.sch]
2022-01-10 Fix problem with opening too many files
    [display.py]
2022-01-10 Turn off MQTT because...🤷
2022-05-04 Moved and restructed files, not sure if things run
    [seven_seg.brd, seven_seg.sch]
2022-05-05 fixed template and completed playable snake
    [main.py]
2022-05-10 WIP: First attempt at main loop
    It isn't correct, but I think it is close...?
    [main.py]
2022-05-10 added frame rate controller to main controller
2022-05-13 fixed input and output queue problem
    [main.py]
2022-05-16 Added breakout, fixed netlab, spiral, and checkerboard
    [main.py]
2022-05-16 fixed a demo, added input queue functionality and stop function calling
    [main.py]
2022-05-16 fixed input queue getting
    [main.py]
2022-05-16 Breakout controlled done and speeds fixed
    [main.py]
2022-05-27 Threading works, multiple cameras works, but issues on switching
    [main.py]
2022-06-01 Fix demo runner to work with new interface
    [main.py]
2022-06-02 Fix breakout queue management
    [main.py]
2022-06-03 Fix get_input_buff and rename it.
    The old implementation did not actually remove items from the queue. I
    created a new function and moved it to a utils folder so that not every
    demo has to implement the same function.
    [main.py]
2022-06-09 Disabled hotplugging logic, doesn't work. Added support for rest of gamepad buttons
2022-06-09 Camera speed dealio
2022-06-09 Diff camera
2022-06-10 Fixing bug in the display code...
    [display.py]
2022-06-15 Made camera stable for kiosk
2022-06-15 Update seven_seg.py
    Quick fix
    [seven_seg.py]
2022-06-15 Thread daemon fix
2022-06-16 Made some printing/logging edits, fixed class description
    [main.py]
2022-06-16 Added fast camera
2022-06-16 Stop previous demo when switching demos in kiosk
2022-06-16 Input hack, to be fixed
    [main.py]
2022-06-17 Add testing flag to demo runner
    When the flag is set, information about the runtime of the demo will be
    printed.
2022-06-17 Fix weird demo time bug
    [main.py]
2022-06-22 Removing camera_fast demo for now
2022-06-23 Boiler plate for yaml config tested with exceptions
2022-06-23 Removed debug print statements from game
2022-06-27 Move all demo classes to be Pascal case
    This conforms with Python conventions for class names.
2022-06-27 Fixing 'NO CAMERA' being stuck on the screen
    [main.py]
2022-06-28 Add a runner to tests all demos
    It just runs the demo for a few ticks to make sure nothing crashes
    [main.py]
2022-06-30 Add self-hosted action to check on a Raspberry Pi
    This will run the test suite on the Raspberry Pi to make sure it runs
    properly on the correct hardware.
2022-06-30 Camera punished
2022-06-30 Fix error with importing pygame
    Moved imports around so that pygame is not accidentally imported when
    running tests.
    [main.py]
2022-07-05 fixing up the snake game and snake ai demo
    [main.py]
2022-07-06 Add keymap for more buttons, added output stream from doom
2022-07-07 Fix logic behind reading queue
    [main.py]
2022-07-07 Checked in kiosk and fixed ai
    [main.py]
2022-07-12 Handle keyboard interrupts and add more logging
2022-07-12 Handle keyboard interrupts
2022-07-14 Finished Intro-landing page
2022-07-14 Intro is landing?
2022-07-19 Handle keyboard interrupt in simulator
2022-07-26 Reset demo time to None for a game
    [main.py]
2022-08-12 Add device tree assets
2022-08-12 camera body added
    [cam-case-sss.stl]
2022-08-12 Another method
    [cam-case-sss.stl, cam-lid-sss.3mf]
2022-08-12 Its not pretty but there it is
    [cam-case-sss.3mf, cam-lid-sss.3mf]
2022-08-12 Camera module media added, fixed three js windows
2022-08-12 Reorganize hardwire files
    [cam-case-sss.3mf, cam-lid-sss.3mf, seven_seg.brd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]
2022-08-12 Finished camera documentation
2022-08-12 Rearrange files and start enclosure
    [cam-case-sss.3mf, cam-lid-sss.3mf]
2022-08-12 Finished enclosure and feet sans 3mf
    [power-board-sss.brd, power-board-sss.sch]
2022-08-12 More schematics and brd images added
    [panel-sss.brd, panel-sss.sch]
2022-08-16 Panel article
    [feet-sss.3mf]
2022-08-23 Catch weird socket error
2022-09-01 Hotfix that prevents issue #25
    [main.py]
2023-02-03 Fixed the screen and added panel ID demo
    [main.py]
2023-06-14 Fix game over logic
    [main.py]
2023-08-24 Fix comments to be compatible with mkdocstring #34
    [display.py]
2023-08-30 Remove unnecessary print
2024-04-26 init of case .3mf files
    [BOTTOM BODY v6.3mf, Big Bracket v3.3mf, Bracket v5.3mf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]
2024-08-19 Fixing minor issue in hangman_ai, changing is_not to != to remove warning
    [main.py]
2024-08-19 Fixed the high score end game state
    [main.py]
2024-08-20 Working on prints
2024-10-22 Fix ai stuck in loop
    [main.py]
2024-10-22 Fix formatting and comments
    [main.py]
2024-10-23 Raise more descriptive error when text is too long
    Fixes #36
    [display.py]
2024-10-24 hotfix to snake ai crashing and not displaying a banner when restarting
    [main.py]
2024-10-25 Only print logs if controllers are there
2024-10-25 Lower the logging level of controllers
    Having debug messages print out every loop seems excessive.
2024-10-25 Fix logo placement for flag as ref'd in #67
    [main.py]
2024-10-25 Fix the order of the demos
    [main.py]
2024-10-31 Fix problem with breakout taking all input from q
    [main.py]
2024-10-31 Fix issue with demo names
    [main.py]
2024-10-31 Change the button to select the demo
2024-11-01 Have select button go to the system queue
2024-11-01 Remove ctrl/cmd button release event
2024-11-03 No longer require demos to be passed into demo
    [main.py]
2025-11-14 Use only log files
    No longer print log messages to stderr
    [main.py]
